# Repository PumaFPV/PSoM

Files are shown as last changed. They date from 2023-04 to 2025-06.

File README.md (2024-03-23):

# PSoM
PSoM, either Pico System On Module, or Puma System On Module for those who prefer.

The goal is to have an easy to integrate MCU + BMS for any kind of projects.
Without attaching points, the SoM is 20mm*20mm. 

## PSoM_ESP32S2_00
Hardware is done and working!

## PSoM_RP2040_00
Schematic is work in progress

##PSoM_ESP32_PICOD4_00
Schematic os work on progress

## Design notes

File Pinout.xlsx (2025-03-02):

 | Gnd |  | Power | Debug | Flash | USB | I2C | SPI | UART | ADC | DAC | IO
Pins | Alternate 1 | Alternate 2 | ESP32S2 | nRF52840 |  | Pins | Alternate 1 | Alternate 2 | ESP32S2 | nRF52840
1 | Gnd |  |  |  |  | 2 | Gnd
3 | Battery temp |  |  |  |  | 4 | Vbat
5 | SPI1_MOSI |  | IO2 | P0.06 |  | 6
7 | SPI1_MISO |  | IO3 | P0.07 |  | 8
9 | SPI1_CLK |  | IO4 | P0.08 |  | 10 | Vbus
11 | SPI1_CS0 |  | IO5 | P1.08 |  | 12
13 | SDA1 |  | IO6 | P0.00 |  | 14 | Vsys
15 | SCL1 |  | IO7 | P0.01 |  | 16
17 | INT | ADC1 | IO8 | P0.30 |  | 18 | 3V3
19 | UART1 | ADC2 | IO9 | P0.04 |  | 20
21 | UART1 | ADC3 | IO10 | P0.05 |  | 22 | Gnd
23 | GPI |  | IO11 | P1.10 |  | 24
25 | GPI |  | IO12 | P0.29 |  | 26 | BOOT0 |  | IO0
27 | GPI |  | IO13 | P0.31 |  | 28 | EN |  | EN
29 | GPI |  | IO14 | P1.13 |  | 30 | GPIO |  | IO33 | P0.26
31 | GPI |  | IO15 | P1.04 |  | 32 | GPIO |  | IO34 | P0.27
33 |  |  | IO16 | P1.15 |  | 34 | SPI2_MOSI | UART TX | IO35 | P0.14
35 | DAC1 |  | IO17 | P0.12 |  | 36 | SPI2_MISO | UART RX | IO36 | P0.15
37 | DAC2 |  | IO18 | P0.11 |  | 38 | SPI2_CLK |  | IO37 | P0.16
39 | GPIO |  | IO21 | P1.09 |  | 40 | SPI2_CS0 |  | IO38 | P0.17
41 | Gnd |  |  |  |  | 42 | SDA2 |  | IO41 | P0.24
43 | SPI_CS1 |  | SPI_CS1 | P0.20 |  | 44 | SCL2 |  | IO39 | P0.25
45 | VDD_SPI |  | VDD_SPI |  |  | 46 | INT |  | IO40 | P1.01
47 | SPI_HD |  | SPI_HD | P0.21 |  | 48 | RX0 | SWDCLK | RX0 | SDWCLK
49 | SPI_WP |  | SPI_WP | P0.23 |  | 50 | TX0 | SWDIO | TX0 | SDWDIO
51 | SPI_CS0 |  | SPI_CS0 | P0.18 |  | 52 | GPIO |  | IO42 | P1.02
53 | SPI_CLK |  | SPI_CLK | P0.19 |  | 54 | Gnd
55 | SPI_Q |  | SPI_Q | P0.22 |  | 56 | D+
57 | SPI_D |  | SPI_D | P1.00 |  | 58 | D-
59 | Gnd |  |  |  |  | 60 | Gnd

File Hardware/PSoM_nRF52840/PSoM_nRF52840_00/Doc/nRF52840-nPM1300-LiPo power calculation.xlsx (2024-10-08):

Config |  |  |  | nPM DCDC reg |  | nRF DCDC reg0 (high voltage mode) |  |  | nRF DCDC reg1 (normal voltage mode)
BMS |  | VBAT |  | VOUT |  | VIN | VOUT |  | VIN | VOUT
nPM1300 |  | 4.20 |  | 3.30 |  |  |  |  |  | 1.30
 |  | 3.80 |  | 3.30 |  |  |  |  |  | 1.30
 |  | 3.70 |  | 3.30 |  |  |  |  |  | 1.30
 |  | 3.50 |  | 3.30 |  |  |  |  |  | 1.30
 |  | 4.20 |  | 2.20 |  |  |  |  |  | 1.30
 |  | 3.80 |  | 2.20 |  |  |  |  |  | 1.30
 |  | 3.70 |  | 2.20 |  |  |  |  |  | 1.30
 |  | 3.50 |  | 2.20 |  |  |  |  |  | 1.30
 |  | 4.20 |  | 1.80 |  |  |  |  |  | 1.30
 |  | 3.80 |  | 1.80 |  |  |  |  |  | 1.30
 |  | 3.70 |  | 1.80 |  |  |  |  |  | 1.30
 |  | 3.50 |  | 1.80 |  |  |  |  |  | 1.30
 |  |  |  |  |  |  |  |  |  | 1.30
 |  |  |  |  |  |  |  |  |  | 1.30
 |  |  |  |  |  |  |  |  |  | 1.30
 |  |  |  |  |  |  |  |  |  | 1.30
BQ25101 |  | 4.20 |  |  |  |  |  |  |  | 1.30
 |  | 3.80 |  |  |  |  |  |  |  | 1.30
 |  | 3.70 |  |  |  |  |  |  |  | 1.30
 |  | 3.50 |  |  |  |  |  |  |  | 1.30
 | vbat | > | npm buck1 | > | nrf vdd | > | reg1 | >1v3
 |  |  | npm buck2 | > | 3v3
 | vbat | > | bq | > | nrf vddH | > | reg0 | > | 3v3
 |  |  |  |  |  |  |  | > | reg1 | > | 1v3

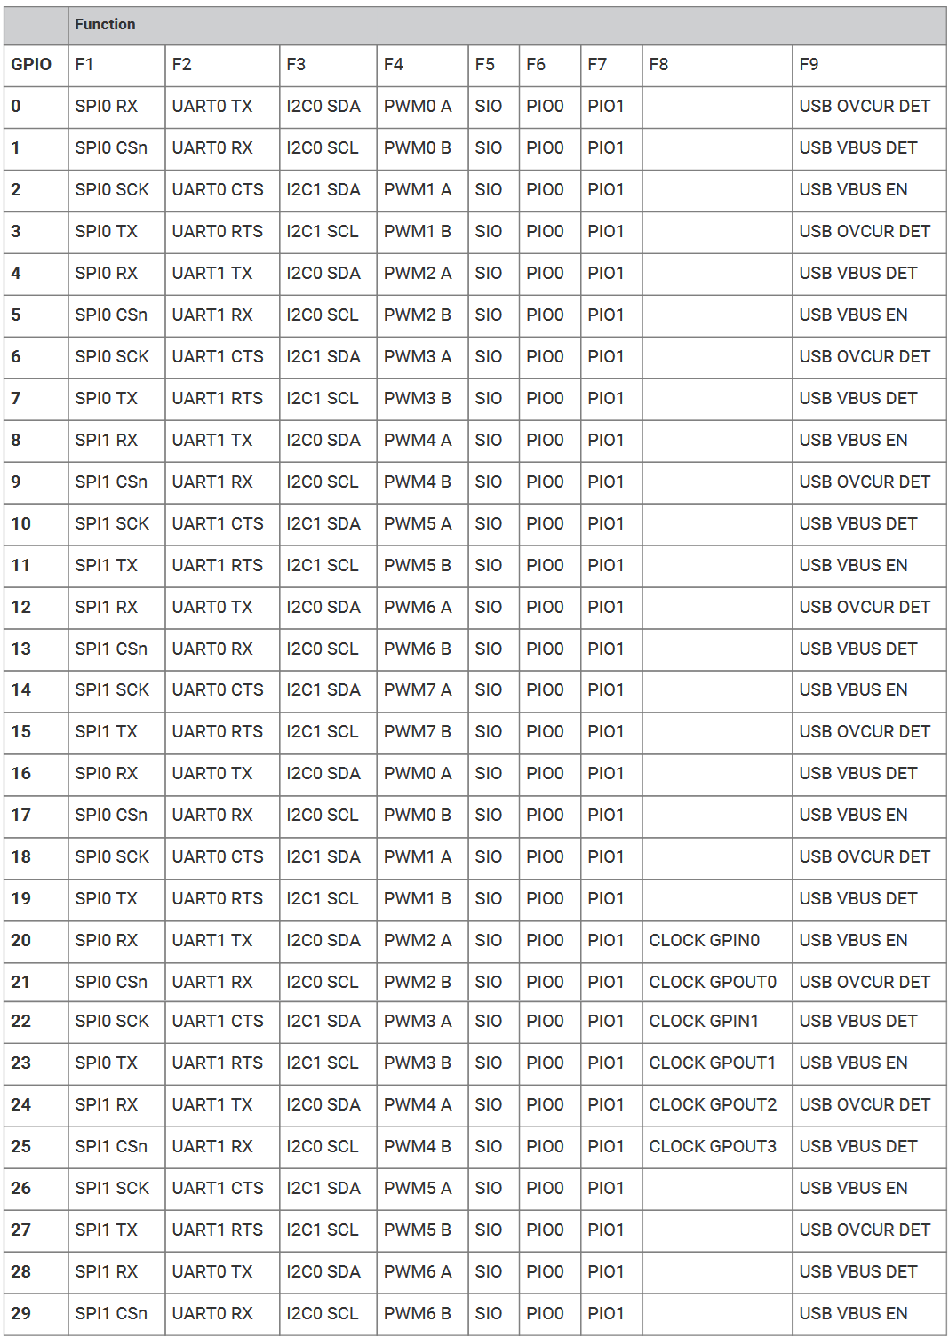
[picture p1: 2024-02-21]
Hardware/PSoM_RP2040/PSoM_RP2040_00/Doc/pinout.png

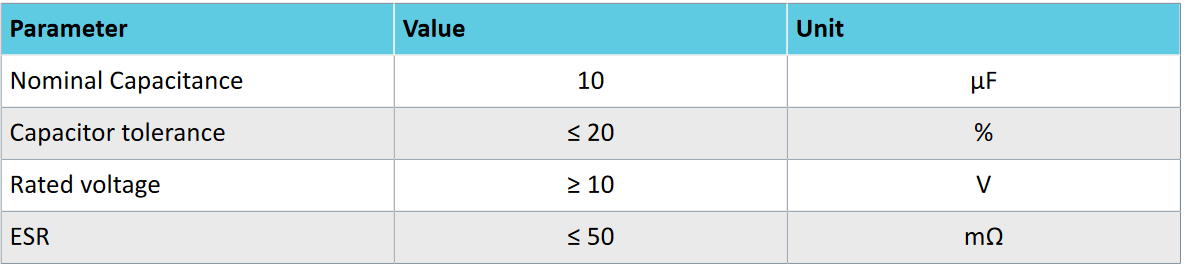
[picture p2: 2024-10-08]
Hardware/PSoM_nRF52840/PSoM_nRF52840_00/Doc/nPM1300 capacitor selection.png

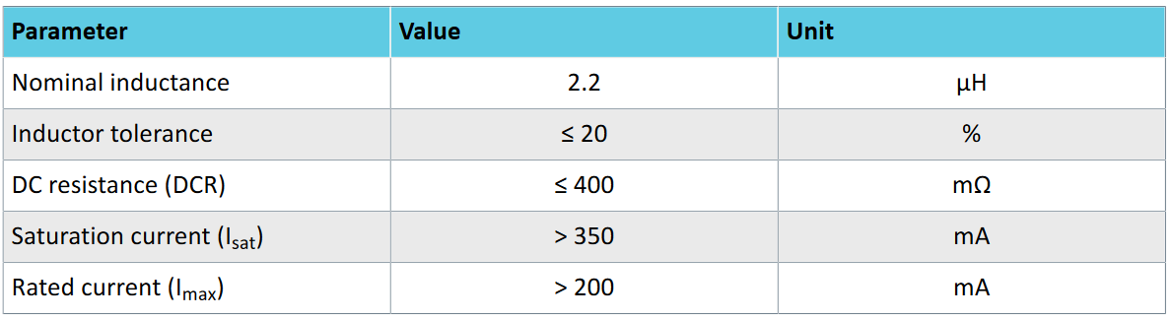
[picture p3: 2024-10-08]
Hardware/PSoM_nRF52840/PSoM_nRF52840_00/Doc/nPM1300 inductor selection.png

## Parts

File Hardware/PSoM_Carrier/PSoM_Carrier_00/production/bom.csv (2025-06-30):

Designator | Footprint | Quantity | Value | LCSC Part #
CS1-P43 | TestPoint_Pad_1.0x1.0mm | 1 | TestPoint
J1 | USB4510031A | 1 | USB4510-03-1-A
J10, J17 | PinHeader_1x06_P2.54mm_Vertical | 2 | Conn_01x06
J11, J18, J20, J21, J7, J9 | PinHeader_1x04_P2.54mm_Vertical | 6 | Conn_01x04
J12, J15, J19 | PinHeader_1x03_P2.54mm_Vertical | 3 | Conn_01x03
J13, J16, J2, J3, J4, J5 | PinHeader_1x02_P2.54mm_Vertical | 6 | Conn_01x02
J14, J8 | PinHeader_1x12_P2.54mm_Vertical | 2 | Conn_01x12
J22 | PinHeader_1x05_P2.54mm_Vertical | 1 | Conn_01x05
J23 | PSoM_ESP32S2_00 | 1 | PSoM_ESP32S2_Carrier_Board
J6 | 532610371 | 1 | 53261-0371
R1, R2 | 0402 | 2 | 5k1
S1, S2 | SKRPABE010 | 2 | SKRPABE010
SW1 | 450405020524 | 1 | 450405020524
U1 | SON127P600X500X80-9N-D | 1 | W25Q128JVPIQ_TR

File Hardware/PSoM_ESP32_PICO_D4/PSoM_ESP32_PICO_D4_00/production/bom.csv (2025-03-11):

Designator | Footprint | Quantity | Value | LCSC Part #
ANT401 | ANTC3216X140N | 1 | 2450AT18A100E
C101, C402, C405 | 0201 | 3 | 100n
C201, C203 | 0603 | 2 | 4u7
C202 | 0603 | 1 | 1u
C301, C302 | 0603 | 2 | 2u2
C401 | 0603 | 1 | 10u
C403, C404 | 0201 | 2 | C
D201, D202, D401 | 0402 | 3 | LED
J101 | DF40C-60DP-0.4V(51) | 1 | DF40C-60DP-0.4V(51)
L401 | 0201 | 1 | L
R1, R2 | 0402 | 2 | R
R103 | 0201 | 1 | 220k
R104 | 0201 | 1 | 470k
R201 | 0402 | 1 | 0
R202 | 0402 | 1 | 36k5
R203 | 0402 | 1 | 590
R204 | 0402 | 1 | 1k1
R205, R206 | 0402 | 2 | 1k5
R207 | 0402 | 1 | 100k
R301 | 0201 | 1 | 0k
R401 | 0402 | 1 | 2k
R402 | 0201 | 1 | 10k
R408, R409 | 0201 | 2 | nu
SW401, SW402 | B3U-1000P | 2 | SW_Push
U201 | QFN50P300X300X100-17N-D | 1 | BQ24075RGTR
U301 | SON40P120X120X60-7N-D | 1 | MIC5528-3.3YMT-T5
U401 | ESP32-PICO-D4_1 | 1 | ESP32-PICO-D4

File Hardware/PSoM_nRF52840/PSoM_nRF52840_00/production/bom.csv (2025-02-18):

Designator | Footprint | Quantity | Value | LCSC Part #
C201, C205, C414, C415 | 0402 | 4 | 1u
C202, C203, C204, L402 | 0603 | 4 | 10u
C206, L201, L202 | 0603 | 3 | 2u2
C207, C208 | 0402 | 2 | 10u
C401, C402 | 0201 | 2 | 12p
C403 | 0201 | 1 | 0p8
C404 | 0201 | 1 | 0p5
C405, C407, C408, C412, C461 | 0201 | 5 | 100n
C406, C420, C421 | 0603 | 3 | 4u7
C409 | 0201 | 1 | 820p
C410, C413 | 0402 | 2 | nc
C411 | 0201 | 1 | 100p
C416 | 0402 | 1 | 47n
D201, D202, D203 | 0402 | 3 | LED
J1 | usb-c-pcb | 1 | Bare PCB USB C
J101 | DF40C-60DP-0.4V(51) | 1 | DF40C-60DP-0.4V(51)
J2 | u.fl | 1 | U.FL-R-SMT-1_40_
J401, J402 | SolderWirePad_1x01_SMD_1x2mm | 2 | Conn_01x01_Pin
L401 | 0201 | 1 | 4n7
L403 | 0402 | 1 | 15n
R203 | 0201 | 1 | 47k
R204 | 0201 | 1 | 470k
R205, R461 | 0201 | 2 | 10k
SW461 | B3U-1000P | 1 | SW_Push
U201 | NPM1300-QEAA-R | 1 | NPM1300-QEAA-R
U401 | Nordic_AQFN-73-1EP_7x7mm_P0.5mm | 1 | nRF52840-QIAA-aQFN73
Y401 | 830108161301_1.6x1.2mm | 1 | 830108161301

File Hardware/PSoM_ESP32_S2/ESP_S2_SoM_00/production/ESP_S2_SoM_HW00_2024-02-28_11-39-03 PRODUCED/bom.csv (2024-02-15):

Designator | Footprint | Quantity | Value | LCSC Part #
ANT401 | ANTC3216X140N | 1 | 2450AT18A100E
C101, C403, C404, C405, C408, C411, C412, C414, C415, C416 | 0201 | 10 | 100n
C201, C203 | 0603 | 2 | 4u7
C202 | 0603 | 1 | 1u
C301, C302 | 0603 | 2 | 2u2
C401, C402 | 0201 | 2 | 15p
C406, C407 | 0201 | 2 | C
C409 | 0603 | 1 | 10u
C410, C413 | 0402 | 2 | 1u
D201, D202, D401 | 0402 | 3 | LED
J101 | DF40C-60DP-0.4V(51) | 1 | DF40C-60DP-0.4V(51)
J102 | usb-c-pcb | 1 | Bare PCB USB C
L401 | 0201 | 1 | L
R1, R2 | 0402 | 2 | R
R101, R102 | 0201 | 2 | 5.1k
R103 | 0201 | 1 | 220k
R104 | 0201 | 1 | 470k
R201 | 0402 | 1 | 0
R202 | 0402 | 1 | 36k5
R203 | 0402 | 1 | 590
R204 | 0402 | 1 | 1k1
R205, R206 | 0402 | 2 | 1k5
R207 | 0402 | 1 | 100k
R301 | 0201 | 1 | 0k
R401 | 0201 | 1 | 0
R402 | 0402 | 1 | 2k
R403, R404 | 0201 | 2 | 10k
R405, R406, R407, R408 | 0201 | 4 | nu
SW401, SW402 | B3U-1000P | 2 | SW_Push
U201 | QFN50P300X300X100-17N-D | 1 | BQ24075RGTR
U301 | SON40P120X120X60-7N-D | 1 | MIC5528-3.3YMT-T5
U401 | QFN40P700X700X90-57N-D | 1 | ESP32-S2FH4
Y601 | Crystal_SMD_2016-4Pin_2.0x1.6mm | 1 | Crystal_GND24_Small

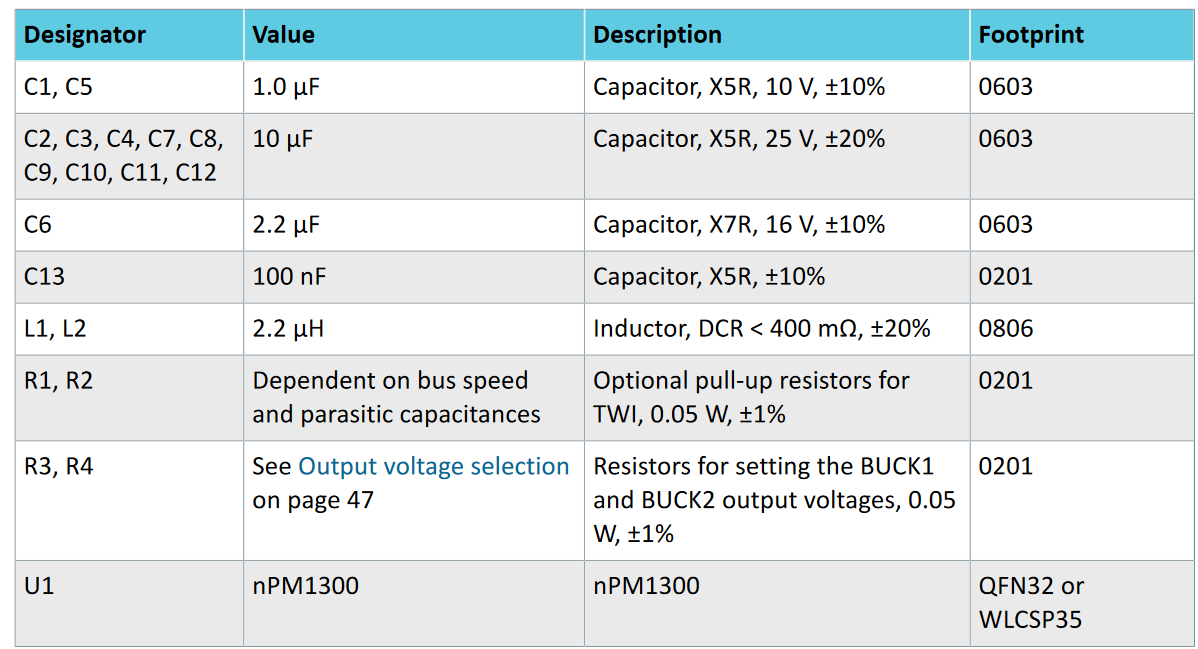
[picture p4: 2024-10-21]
Hardware/PSoM_nRF52840/PSoM_nRF52840_00/Doc/nPM1300 component selection.png

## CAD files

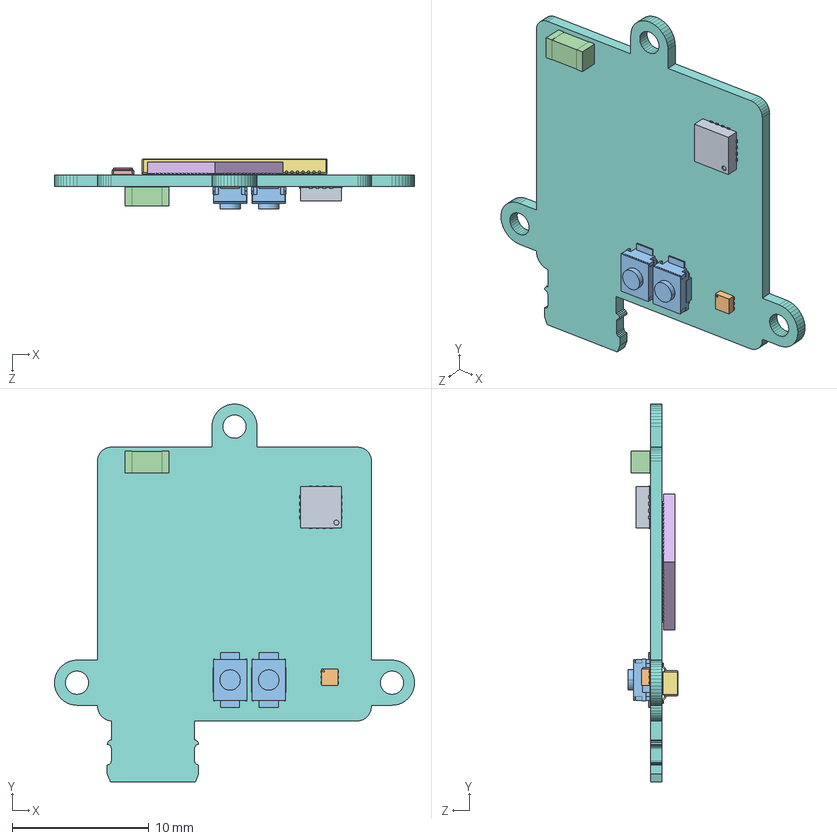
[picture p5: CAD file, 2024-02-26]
Hardware/PSoM_ESP32_PICO_D4/PSoM_ESP32_PICO_D4_00/Mecha/PSoM_ESP32S2_00.SLDASM
26.3 x 27.6 x 3.65 mm
COMPOUND.step
COMPOUND-0.step
SOLID.step x 2
COMPOUND-1.step
COMPOUND-2.step
COMPOUND-3.step
SOLID-4.step
PCB.step

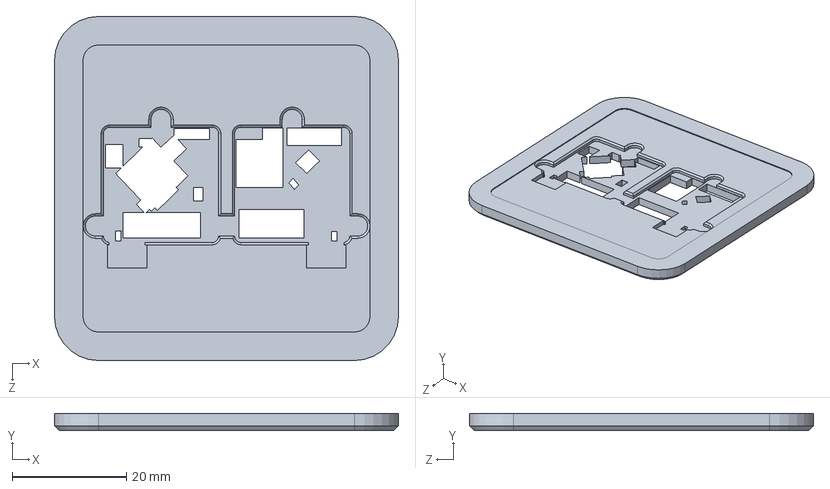
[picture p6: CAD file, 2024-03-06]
Hardware/PSoM_ESP32_S2/ESP_S2_SoM_00/production/stencil holder.SLDPRT
60.3 x 3.00 x 60.3 mm

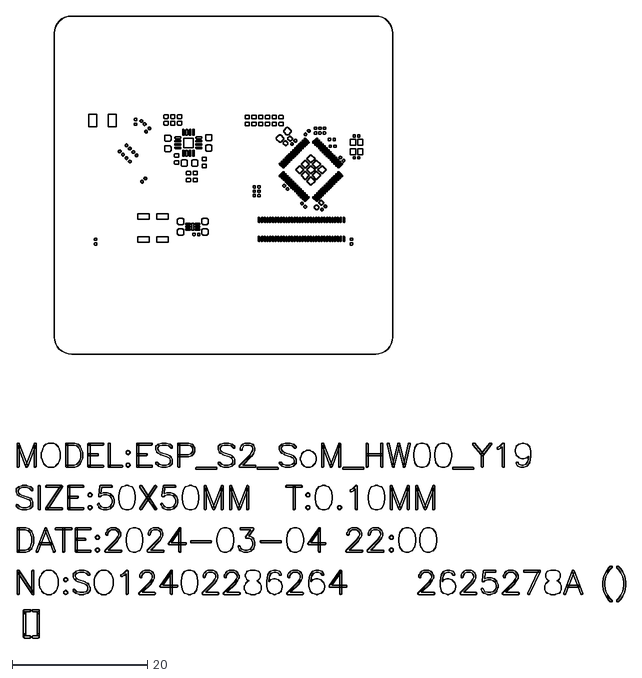
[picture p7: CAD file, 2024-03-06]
Hardware/PSoM_ESP32_S2/ESP_S2_SoM_00/production/SO12402286264/so12402286264A.DXF
90.2 x 91.9

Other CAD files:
Hardware/PSoM_ESP32_PICO_D4/PSoM_ESP32_PICO_D4_00/Mecha/PSoM_ESP32S2_00.DXF
Hardware/PSoM_ESP32_PICO_D4/PSoM_ESP32_PICO_D4_00/Mecha/PSoM_ESP32S2_00.SLDDRW
Hardware/PSoM_ESP32_S2/ESP_S2_SoM_00/production/stencil holder.STL

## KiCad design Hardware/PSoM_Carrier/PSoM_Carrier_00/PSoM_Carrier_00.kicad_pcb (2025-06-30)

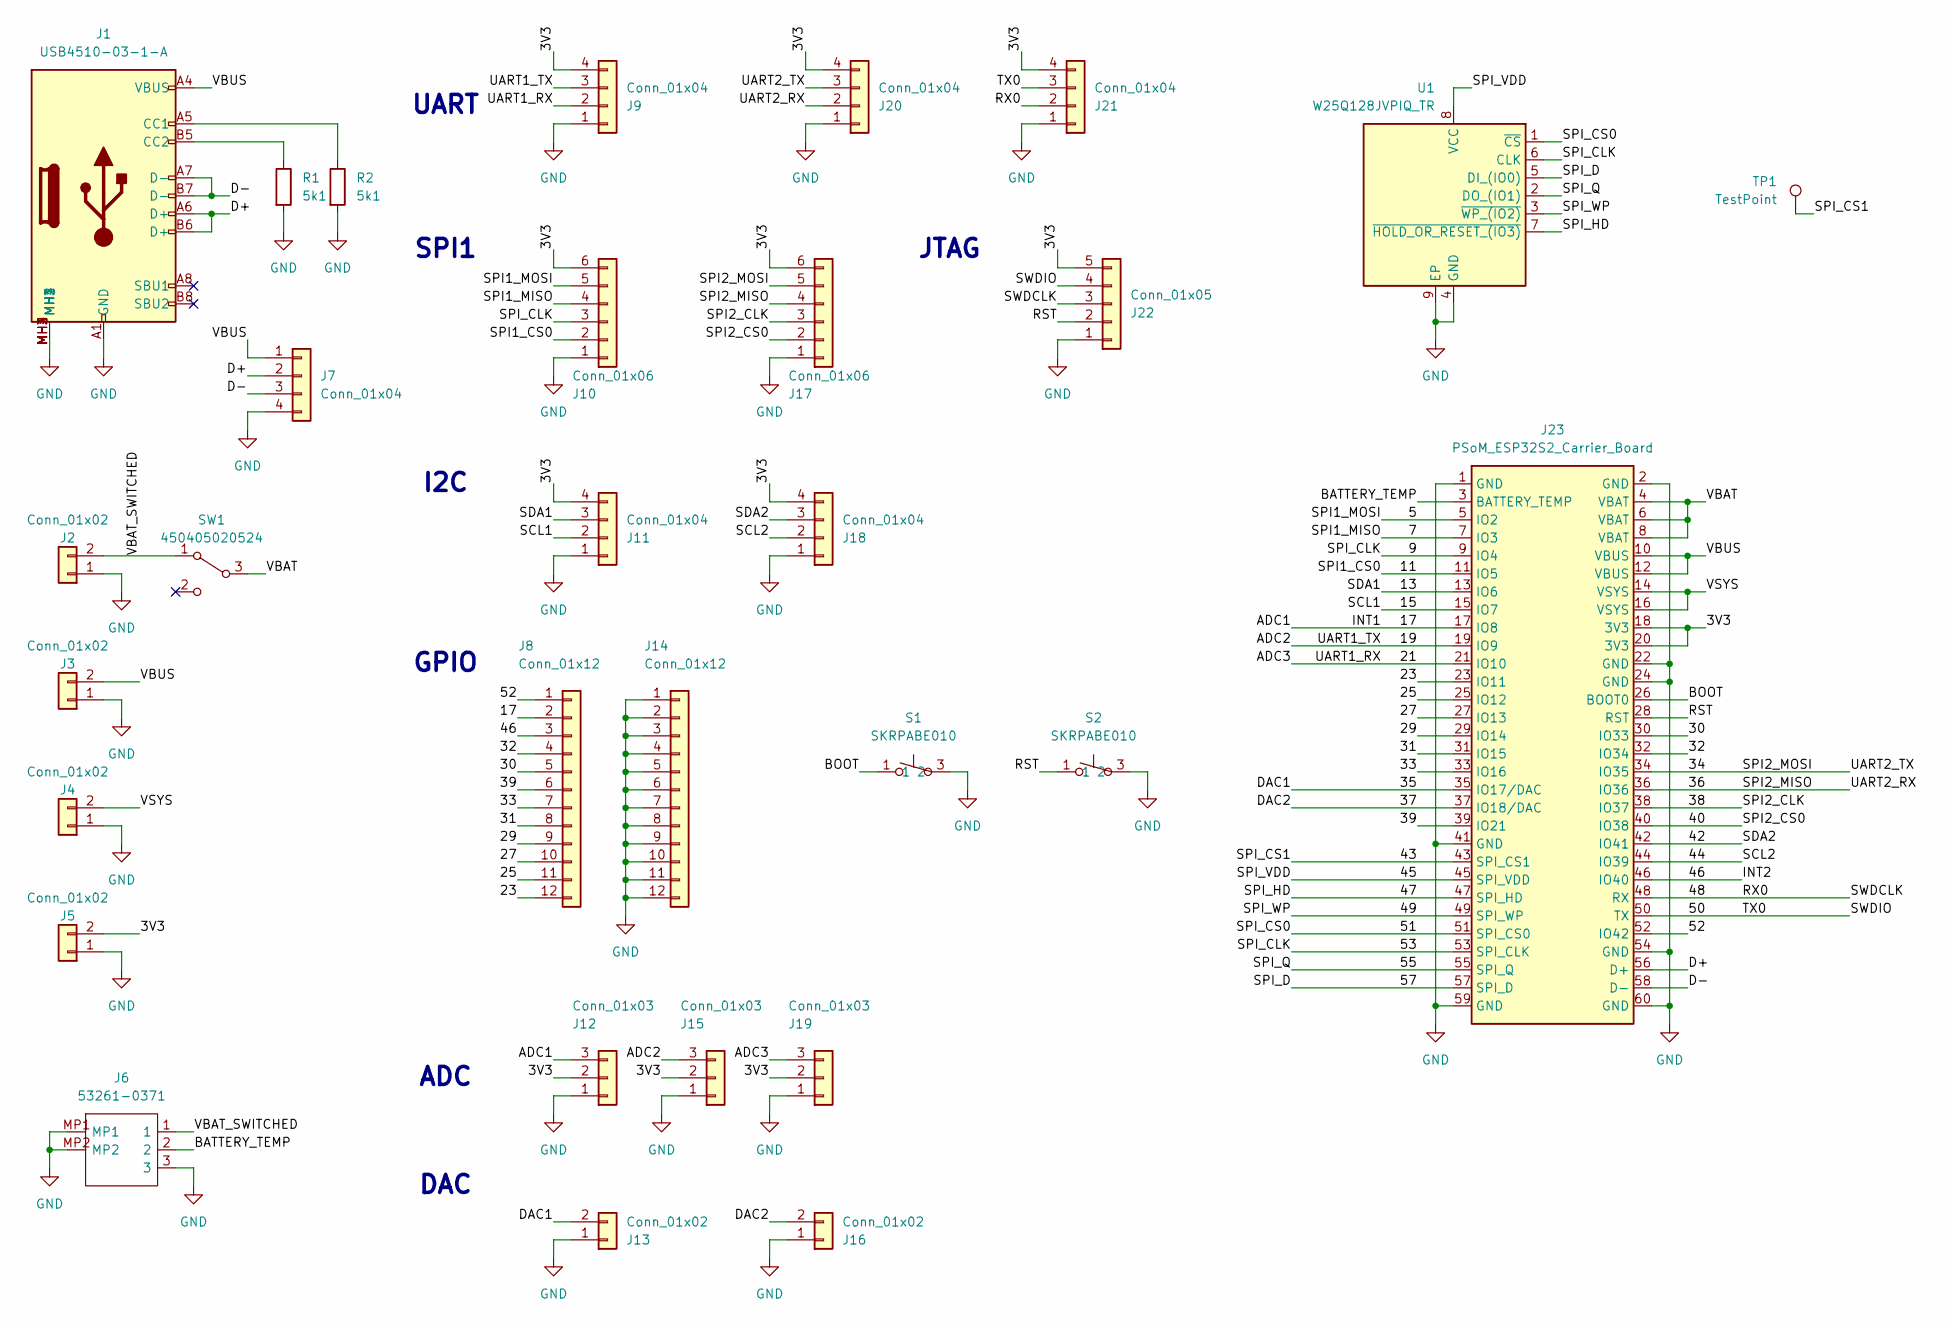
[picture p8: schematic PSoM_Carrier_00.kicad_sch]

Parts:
J1: USB4510-03-1-A; USB4510031A; Mouser Part Number 640-USB4510031A
J2, J3, J4, J5, J13, J16: Conn_01x02; PinHeader_1x02_P2.54mm_Vertical
J6: 53261-0371; 532610371; Mouser Part Number 538-53261-0371
J7, J9, J11, J18, J20, J21: Conn_01x04; PinHeader_1x04_P2.54mm_Vertical
J8, J14: Conn_01x12; PinHeader_1x12_P2.54mm_Vertical
J10, J17: Conn_01x06; PinHeader_1x06_P2.54mm_Vertical
J12, J15, J19: Conn_01x03; PinHeader_1x03_P2.54mm_Vertical
J22: Conn_01x05; PinHeader_1x05_P2.54mm_Vertical
J23: PSoM_ESP32S2_Carrier_Board; PSoM_ESP32S2_00
R1, R2: 5k1; R_0402_1005Metric
S1, S2: SKRPABE010; Mouser Part Number 688-SKRPAB
SW1: 450405020524
TP1: TestPoint; TestPoint_Pad_1.0x1.0mm
U1: W25Q128JVPIQ_TR; SON127P600X500X80-9N-D; Mouser Part Number 454-W25Q128JVPIQTR

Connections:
/3V3: J5.2, J9.4, J10.6, J11.4, J12.2, J15.2, J17.6, J18.4, J19.2, J20.4, J21.4, J22.5, J23.18 (3V3), J23.20 (3V3)
/5: J10.5, J23.5 (IO2)
/7: J10.4, J23.7 (IO3)
/11: J10.2, J23.11 (IO5)
/13: J11.3, J23.13 (IO6)
/15: J11.2, J23.15 (IO7)
/17: J8.2, J12.3, J23.17 (IO8)
/19: J9.3, J15.3, J23.19 (IO9)
/21: J9.2, J19.3, J23.21 (IO10)
/23: J8.12, J23.23 (IO11)
/25: J8.11, J23.25 (IO12)
/27: J8.10, J23.27 (IO13)
/29: J8.9, J23.29 (IO14)
/30: J8.5, J23.30 (IO33)
/31: J8.8, J23.31 (IO15)
/32: J8.4, J23.32 (IO34)
/33: J8.7, J23.33 (IO16)
/34: J17.5, J20.3, J23.34 (IO35)
/35: J13.2, J23.35 (IO17/DAC)
/36: J17.4, J20.2, J23.36 (IO36)
/37: J16.2, J23.37 (IO18/DAC)
/38: J17.3, J23.38 (IO37)
/39: J8.6, J23.39 (IO21)
/40: J17.2, J23.40 (IO38)
/42: J18.3, J23.42 (IO41)
/43: J23.43 (SPI_CS1), TP1.1; also elsewhere on the board
/44: J18.2, J23.44 (IO39)
/45: J23.45 (SPI_VDD), U1.8 (VCC)
/46: J8.3, J23.46 (IO40)
/47: J23.47 (SPI_HD), U1.7 (~HOLD_OR_RESET_(IO3))
/48: J21.2, J22.3, J23.48 (RX)
/49: J23.49 (SPI_WP), U1.3 (~WP_(IO2))
/50: J21.3, J22.4, J23.50 (TX)
/51: J23.51 (SPI_CS0), U1.1 (~CS)
/52: J8.1, J23.52 (IO42)
/53: J10.3, J23.9 (IO4), J23.53 (SPI_CLK), U1.6 (CLK)
/55: J23.55 (SPI_Q), U1.2 (DO_(IO1))
/57: J23.57 (SPI_D), U1.5 (DI_(IO0))
/BATTERY_TEMP: J6.2, J23.3 (BATTERY_TEMP)
/BOOT: J23.26 (BOOT0), S1.1, S1.2 (1)
/D+: J1.A6 (D+), J1.B6 (D+), J7.2, J23.56 (D+)
/D-: J1.A7 (D-), J1.B7 (D-), J7.3, J23.58 (D-)
/RST: J22.2, J23.28 (RST), S2.1, S2.2 (1)
/VBAT: J23.4 (VBAT), J23.6 (VBAT), J23.8 (VBAT), SW1.3 (B)
/VBAT_SWITCHED: J2.2, J6.1, SW1.1 (A)
/VBUS: J1.A4 (VBUS), J1.A9 (VBUS), J1.B4 (VBUS), J1.B9 (VBUS), J3.2, J7.1, J23.10 (VBUS), J23.12 (VBUS)
/VSYS: J4.2, J23.14 (VSYS), J23.16 (VSYS)
GND: J1.A1 (GND), J1.A12 (GND), J1.B1 (GND), J1.B12 (GND), J1.MH1, J1.MH2, J1.MH3, J1.MH4, J2.1, J3.1, J4.1, J5.1, J6.3, J6.MP1, J6.MP2, J7.4, J9.1, J10.1, J11.1, J12.1, J13.1, J14.1, J14.2, J14.3, J14.4, J14.5, J14.6, J14.7, J14.8, J14.9, J14.10, J14.11, J14.12, J15.1, J16.1, J17.1, J18.1, J19.1, J20.1, J21.1, J22.1, J23.1 (GND), J23.2 (GND), J23.22 (GND), J23.24 (GND), J23.41 (GND), J23.54 (GND), J23.59 (GND), J23.60 (GND), R1.2, R2.2, S1.3 (2), S1.4 (2), S2.3 (2), S2.4 (2), U1.4 (GND), U1.9 (EP)
unnamed: J1.A5 (CC1), R2.1
unnamed: J1.B5 (CC2), R1.1

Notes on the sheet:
ADC
DAC
I2C
JTAG
SPI1
GPIO
UART

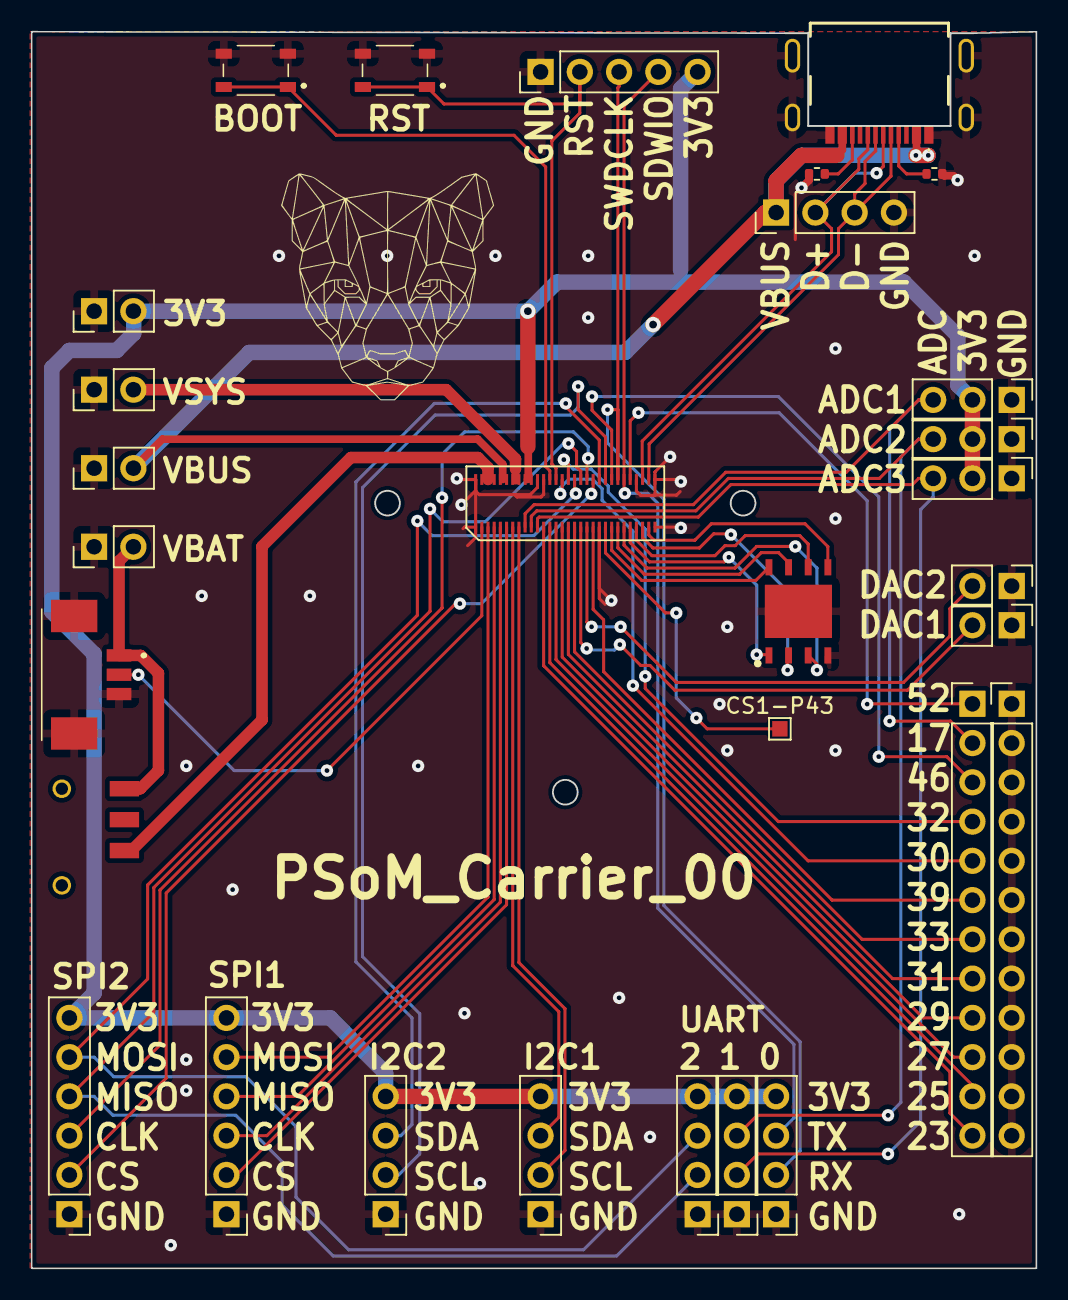
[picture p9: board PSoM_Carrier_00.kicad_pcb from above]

Board: 2 copper layers, 65.0 x 80.0 mm, 30 parts (0 on the bottom side), 50 nets.

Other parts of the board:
CS1-P43: TestPoint; TestPoint_Pad_1.0x1.0mm

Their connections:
/43: CS1-P43.1; also elsewhere on the board

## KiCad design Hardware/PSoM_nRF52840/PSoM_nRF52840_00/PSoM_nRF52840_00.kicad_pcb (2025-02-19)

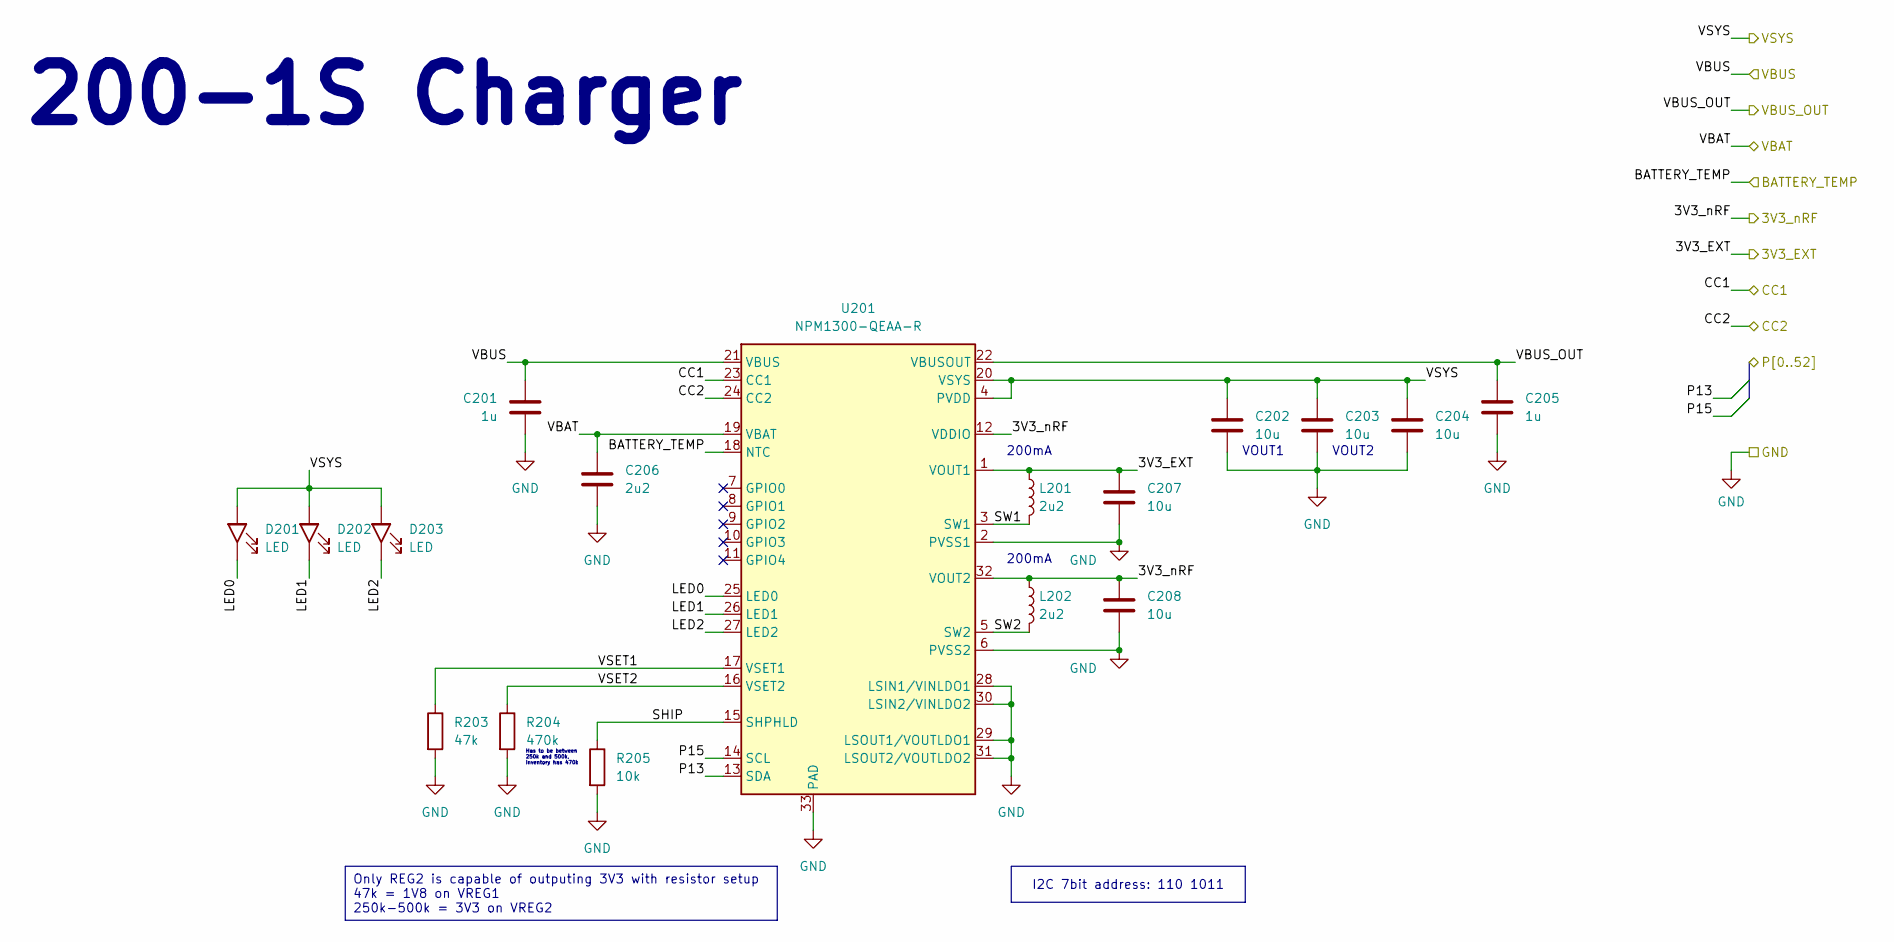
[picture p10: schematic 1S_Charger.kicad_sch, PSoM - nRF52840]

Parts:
C201, C205: 1u; C_0402_1005Metric
C202, C203, C204: 10u; C_0603_1608Metric
C206: 2u2; C_0603_1608Metric
C207: 10u; C_0402_1005Metric
C208: 10u; C_0402_1005Metric_Pad0.74x0.62mm_HandSolder
D201, D202, D203: LED; LED_0402_1005Metric
L201, L202: 2u2; L_0603_1608Metric
R203: 47k; R_0201_0603Metric
R204: 470k; R_0201_0603Metric
R205: 10k; R_0201_0603Metric
U201: NPM1300-QEAA-R; Mouser Part Number 949-NPM1300-QEAA-R

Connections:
+3V3: C207.1, L201.1, U201.1 (VOUT1); also elsewhere on the board
/100_Connectors/BATTERY_TEMP: U201.18 (NTC); also elsewhere on the board
/100_Connectors/CC1: U201.23 (CC1); also elsewhere on the board
/100_Connectors/CC2: U201.24 (CC2); also elsewhere on the board
/100_Connectors/VBAT: C206.1, U201.19 (VBAT); also elsewhere on the board
/100_Connectors/VSYS: C202.1, C203.1, C204.1, D201.1 (A), D202.1 (A), D203.1 (A), U201.4 (PVDD), U201.20 (VSYS); also elsewhere on the board
/200_1S_Charger/3V3_nRF: C208.1, L202.1, U201.12 (VDDIO), U201.32 (VOUT2); also elsewhere on the board
/200_1S_Charger/LED0: D201.2 (K), U201.25 (LED0)
/200_1S_Charger/LED1: D202.2 (K), U201.26 (LED1)
/200_1S_Charger/LED2: D203.2 (K), U201.27 (LED2)
/200_1S_Charger/SHIP: R205.1, U201.15 (SHPHLD)
/200_1S_Charger/SW1: L201.2, U201.3 (SW1)
/200_1S_Charger/SW2: L202.2, U201.5 (SW2)
/200_1S_Charger/VBUS_OUT: C205.1, U201.22 (VBUSOUT); also elsewhere on the board
/200_1S_Charger/VSET1: R203.1, U201.17 (VSET1)
/200_1S_Charger/VSET2: R204.1, U201.16 (VSET2)
GND: C201.1, C202.2, C203.2, C204.2, C205.2, C206.2, C207.2, C208.2, R203.2, R204.2, R205.2, U201.2 (PVSS1), U201.6 (PVSS2), U201.28 (LSIN1/VINLDO1), U201.29 (LSOUT1/VOUTLDO1), U201.30 (LSIN2/VINLDO2), U201.31 (LSOUT2/VOUTLDO2), U201.33 (PAD); also elsewhere on the board
P13: U201.13 (SDA); also elsewhere on the board
P15: U201.14 (SCL); also elsewhere on the board
VBUS: C201.2, U201.21 (VBUS); also elsewhere on the board

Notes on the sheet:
Only REG2 is capable of outputing 3V3 with resistor setup 47k = 1V8 on VREG1 250k-500k = 3V3 on VREG2
I2C 7bit address: 110 1011
200-1S Charger
200mA
Has to be between 250k and 500k, Inventory has 470k
VOUT1
VOUT2

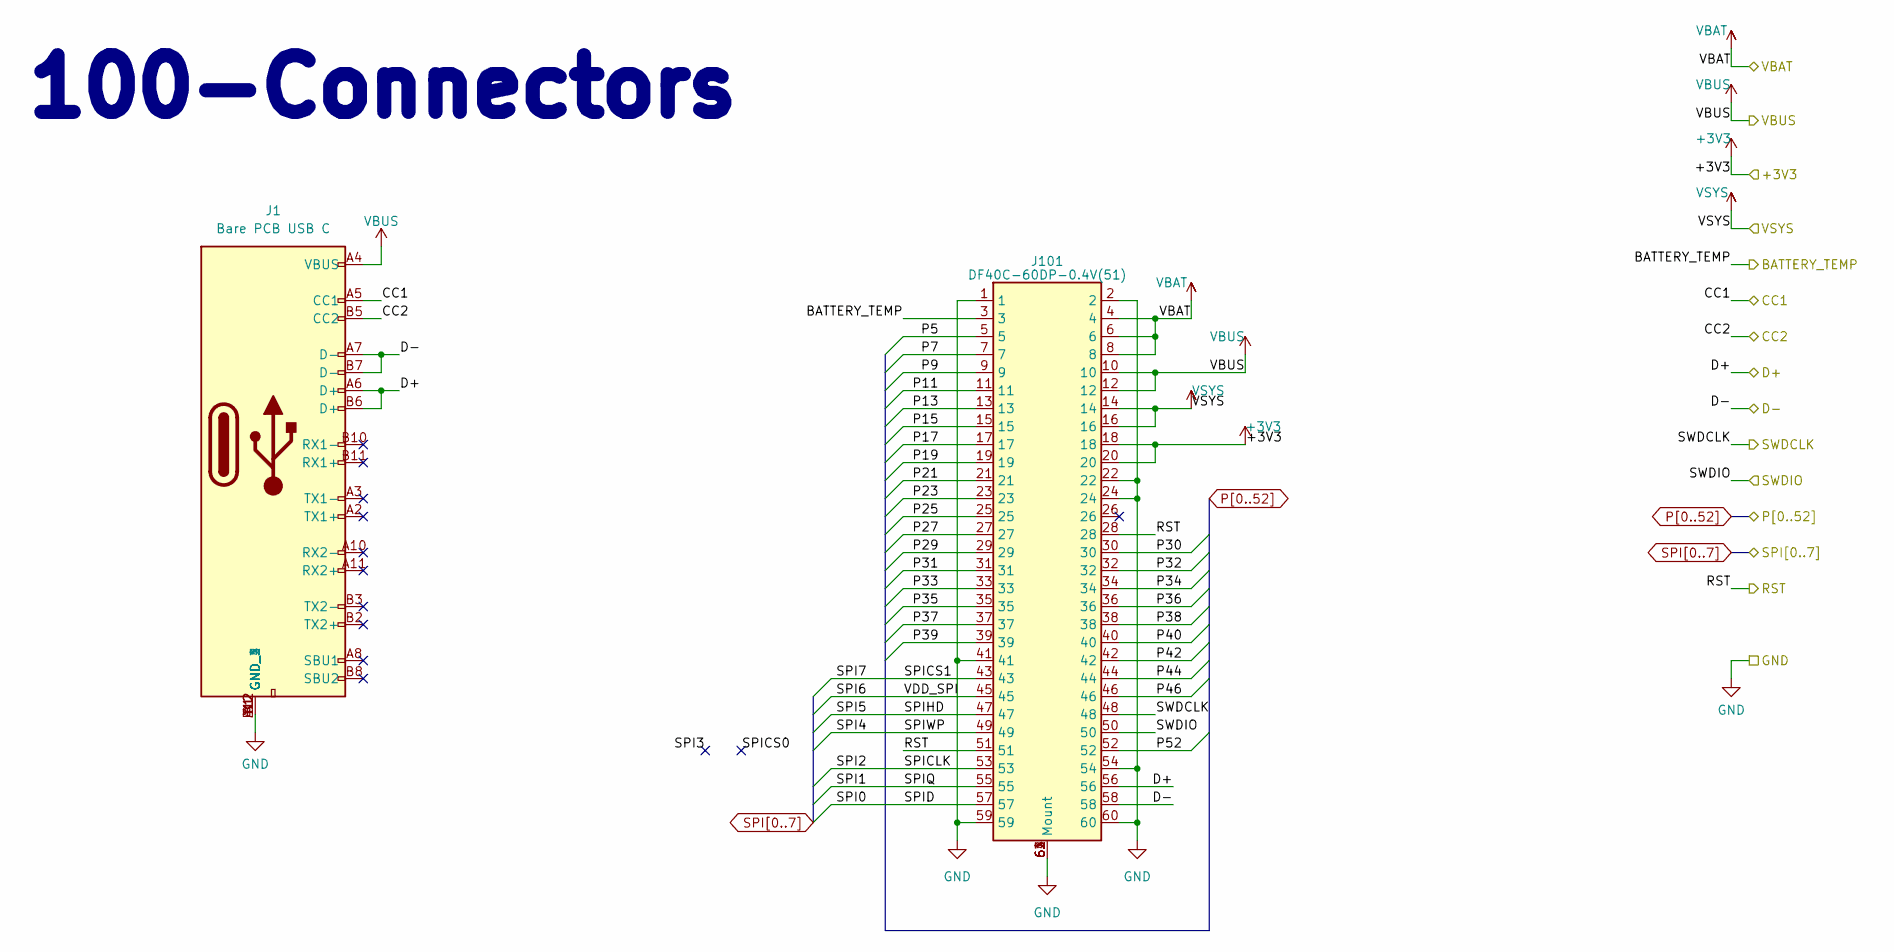
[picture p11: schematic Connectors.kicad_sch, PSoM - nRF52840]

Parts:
J1: Bare PCB USB C; usb-c-pcb; Mouser Part Number 640-USB4510031A
J101: DF40C-60DP-0.4V(51)

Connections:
+3V3: J101.18, J101.20; also elsewhere on the board
/100_Connectors/BATTERY_TEMP: J101.3; also elsewhere on the board
/100_Connectors/CC1: J1.A5 (CC1); also elsewhere on the board
/100_Connectors/CC2: J1.B5 (CC2); also elsewhere on the board
/100_Connectors/D+: J1.A6 (D+), J1.B6 (D+), J101.56; also elsewhere on the board
/100_Connectors/D-: J1.A7 (D-), J1.B7 (D-), J101.58; also elsewhere on the board
/100_Connectors/RST: J101.28, J101.51; also elsewhere on the board
/100_Connectors/SWDCLK: J101.48; also elsewhere on the board
/100_Connectors/SWDIO: J101.50; also elsewhere on the board
/100_Connectors/VBAT: J101.4, J101.6, J101.8; also elsewhere on the board
/100_Connectors/VSYS: J101.14, J101.16; also elsewhere on the board
GND: J1.A1 (GND_1), J1.A12 (GND_2), J1.B1 (GND_3), J1.B12 (GND_4), J101.1, J101.2, J101.22, J101.24, J101.41, J101.54, J101.59, J101.60, J101.61 (Mount), J101.62, J101.63, J101.64; also elsewhere on the board
P5: J101.5; also elsewhere on the board
P7: J101.7; also elsewhere on the board
P9: J101.9; also elsewhere on the board
P11: J101.11; also elsewhere on the board
P13: J101.13; also elsewhere on the board
P15: J101.15; also elsewhere on the board
P17: J101.17; also elsewhere on the board
P19: J101.19; also elsewhere on the board
P21: J101.21; also elsewhere on the board
P23: J101.23; also elsewhere on the board
P25: J101.25; also elsewhere on the board
P27: J101.27; also elsewhere on the board
P29: J101.29; also elsewhere on the board
P30: J101.30; also elsewhere on the board
P31: J101.31; also elsewhere on the board
P32: J101.32; also elsewhere on the board
P33: J101.33; also elsewhere on the board
P34: J101.34; also elsewhere on the board
P35: J101.35; also elsewhere on the board
P36: J101.36; also elsewhere on the board
P37: J101.37; also elsewhere on the board
P38: J101.38; also elsewhere on the board
P39: J101.39; also elsewhere on the board
P40: J101.40; also elsewhere on the board
P42: J101.42; also elsewhere on the board
P44: J101.44; also elsewhere on the board
P46: J101.46; also elsewhere on the board
P52: J101.52; also elsewhere on the board
SPI0: J101.57; also elsewhere on the board
SPI1: J101.55; also elsewhere on the board
SPI2: J101.53; also elsewhere on the board
SPI4: J101.49; also elsewhere on the board
SPI5: J101.47; also elsewhere on the board
SPI6: J101.45
SPI7: J101.43; also elsewhere on the board
VBUS: J1.A4 (VBUS), J1.A9 (VBUS), J1.B4 (VBUS), J1.B9 (VBUS), J101.10, J101.12; also elsewhere on the board

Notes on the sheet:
100-Connectors

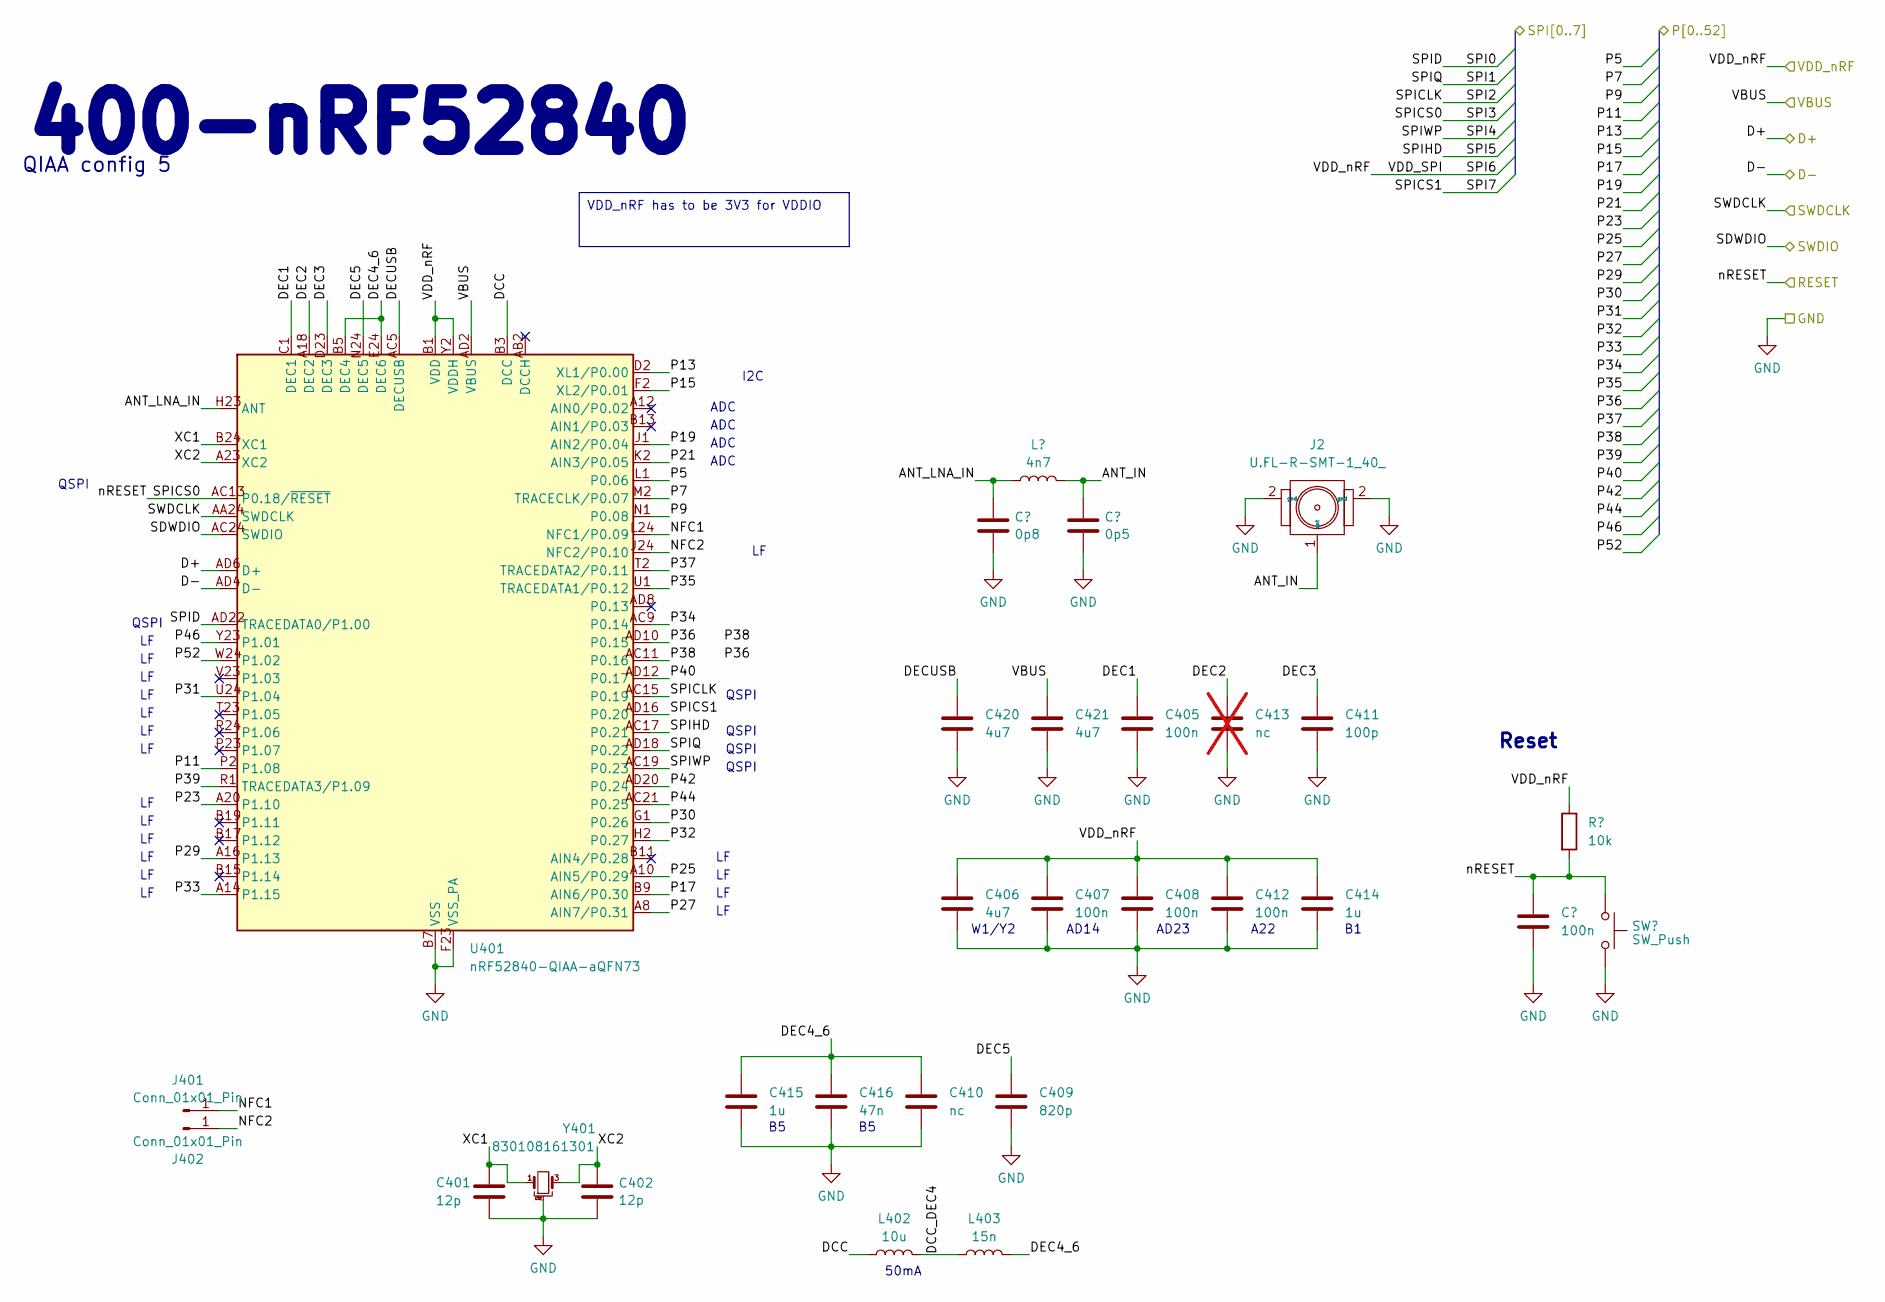
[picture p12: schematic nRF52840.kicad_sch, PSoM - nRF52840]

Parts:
C401, C402: 12p; C_0201_0603Metric
C403: 0p8; C_0201_0603Metric
C404: 0p5; C_0201_0603Metric
C405, C407, C408, C412, C461: 100n; C_0201_0603Metric
C406, C420, C421: 4u7; C_0603_1608Metric
C409: 820p; C_0201_0603Metric
C410: nc; C_0402_1005Metric
C411: 100p; C_0201_0603Metric
C413: nc; C_0402_1005Metric; not fitted
C414, C415: 1u; C_0402_1005Metric
C416: 47n; C_0402_1005Metric
J2: U.FL-R-SMT-1_40_; u.fl; Mouser Part Number 798-UFLRSMT140
J401, J402: Conn_01x01_Pin; SolderWirePad_1x01_SMD_1x2mm
L401: 4n7; L_0201_0603Metric
L402: 10u; L_0603_1608Metric
L403: 15n; L_0402_1005Metric
R461: 10k; R_0201_0603Metric
SW461: SW_Push; B3U-1000P
U401: nRF52840-QIAA-aQFN73; Nordic_AQFN-73-1EP_7x7mm_P0.5mm
Y401: 830108161301; 830108161301_1.6x1.2mm

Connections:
/100_Connectors/D+: U401.AD6 (D+); also elsewhere on the board
/100_Connectors/D-: U401.AD4 (D-); also elsewhere on the board
/100_Connectors/RST: C461.1, R461.2, SW461.1, U401.AC13 (P0.18/~RESET); also elsewhere on the board
/100_Connectors/SWDCLK: U401.AA24 (SWDCLK); also elsewhere on the board
/100_Connectors/SWDIO: U401.AC24 (SWDIO); also elsewhere on the board
/200_1S_Charger/3V3_nRF: C406.1, C407.1, C408.1, C412.1, C414.1, R461.1, U401.A22 (VDD), U401.AD14 (VDD), U401.AD23 (VDD), U401.B1 (VDD), U401.W1 (VDD), U401.Y2 (VDDH); also elsewhere on the board
/200_1S_Charger/VBUS_OUT: C421.1, U401.AD2 (VBUS); also elsewhere on the board
/400-nRF52840/ANT_IN: C404.1, J2.1 (ant), L401.1
/400-nRF52840/ANT_LNA_IN: C403.1, L401.2, U401.H23 (ANT)
/400-nRF52840/DCC: L402.1, U401.B3 (DCC)
/400-nRF52840/DCC_DEC4: L402.2, L403.1
/400-nRF52840/DEC1: C405.1, U401.C1 (DEC1)
/400-nRF52840/DEC2: C413.1, U401.A18 (DEC2)
/400-nRF52840/DEC3: C411.1, U401.D23 (DEC3)
/400-nRF52840/DEC4_6: C410.1, C415.1, C416.1, L403.2, U401.B5 (DEC4), U401.E24 (DEC6)
/400-nRF52840/DEC5: C409.1, U401.N24 (DEC5)
/400-nRF52840/DECUSB: C420.1, U401.AC5 (DECUSB)
/400-nRF52840/NFC1: J401.1, U401.L24 (NFC1/P0.09)
/400-nRF52840/NFC2: J402.1, U401.J24 (NFC2/P0.10)
/400-nRF52840/XC1: C401.1, U401.B24 (XC1), Y401.1
/400-nRF52840/XC2: C402.1, U401.A23 (XC2), Y401.3
GND: C401.2, C402.2, C403.2, C404.2, C405.2, C406.2, C407.2, C408.2, C409.2, C410.2, C411.2, C412.2, C413.2, C414.2, C415.2, C416.2, C420.2, C421.2, C461.2, J2.2 (gnd), SW461.2, U401.B7 (VSS), U401.EP (VSS), U401.F23 (VSS_PA), Y401.2, Y401.4; also elsewhere on the board
P5: U401.L1 (P0.06); also elsewhere on the board
P7: U401.M2 (TRACECLK/P0.07); also elsewhere on the board
P9: U401.N1 (P0.08); also elsewhere on the board
P11: U401.P2 (P1.08); also elsewhere on the board
P13: U401.D2 (XL1/P0.00); also elsewhere on the board
P15: U401.F2 (XL2/P0.01); also elsewhere on the board
P17: U401.B9 (AIN6/P0.30); also elsewhere on the board
P19: U401.J1 (AIN2/P0.04); also elsewhere on the board
P21: U401.K2 (AIN3/P0.05); also elsewhere on the board
P23: U401.A20 (P1.10); also elsewhere on the board
P25: U401.A10 (AIN5/P0.29); also elsewhere on the board
P27: U401.A8 (AIN7/P0.31); also elsewhere on the board
P29: U401.A16 (P1.13); also elsewhere on the board
P30: U401.G1 (P0.26); also elsewhere on the board
P31: U401.U24 (P1.04); also elsewhere on the board
P32: U401.H2 (P0.27); also elsewhere on the board
P33: U401.A14 (P1.15); also elsewhere on the board
P34: U401.AC9 (P0.14); also elsewhere on the board
P35: U401.U1 (TRACEDATA1/P0.12); also elsewhere on the board
P36: U401.AD10 (P0.15); also elsewhere on the board
P37: U401.T2 (TRACEDATA2/P0.11); also elsewhere on the board
P38: U401.AC11 (P0.16); also elsewhere on the board
P39: U401.R1 (TRACEDATA3/P1.09); also elsewhere on the board
P40: U401.AD12 (P0.17); also elsewhere on the board
P42: U401.AD20 (P0.24); also elsewhere on the board
P44: U401.AC21 (P0.25); also elsewhere on the board
P46: U401.Y23 (P1.01); also elsewhere on the board
P52: U401.W24 (P1.02); also elsewhere on the board
SPI0: U401.AD22 (TRACEDATA0/P1.00); also elsewhere on the board
SPI1: U401.AD18 (P0.22); also elsewhere on the board
SPI2: U401.AC15 (P0.19); also elsewhere on the board
SPI4: U401.AC19 (P0.23); also elsewhere on the board
SPI5: U401.AC17 (P0.21); also elsewhere on the board
SPI7: U401.AD16 (P0.20); also elsewhere on the board

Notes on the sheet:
VDD_nRF has to be 3V3 for VDDIO
I2C
ADC
AD23
QSPI
Reset
A22
400-nRF52840
50mA
W1/Y2
AD14
QIAA config 5

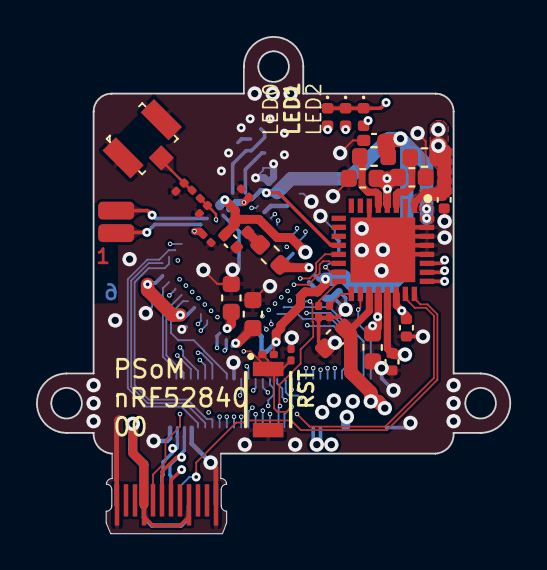
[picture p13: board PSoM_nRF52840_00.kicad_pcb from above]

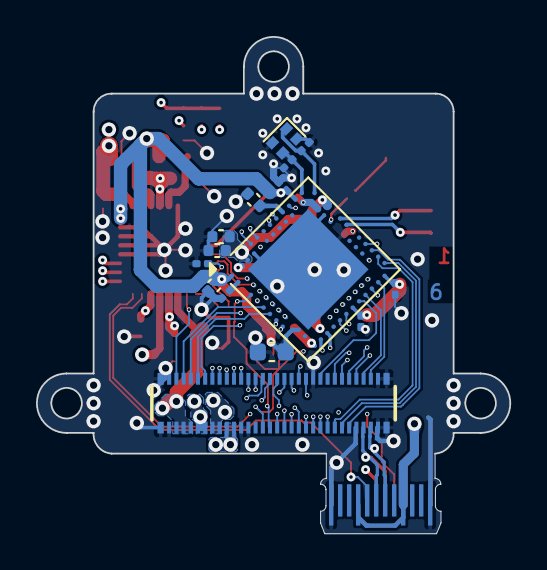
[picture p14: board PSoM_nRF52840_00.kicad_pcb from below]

Board: 6 copper layers, 26.3 x 27.6 mm, 48 parts (15 on the bottom side), 71 nets.

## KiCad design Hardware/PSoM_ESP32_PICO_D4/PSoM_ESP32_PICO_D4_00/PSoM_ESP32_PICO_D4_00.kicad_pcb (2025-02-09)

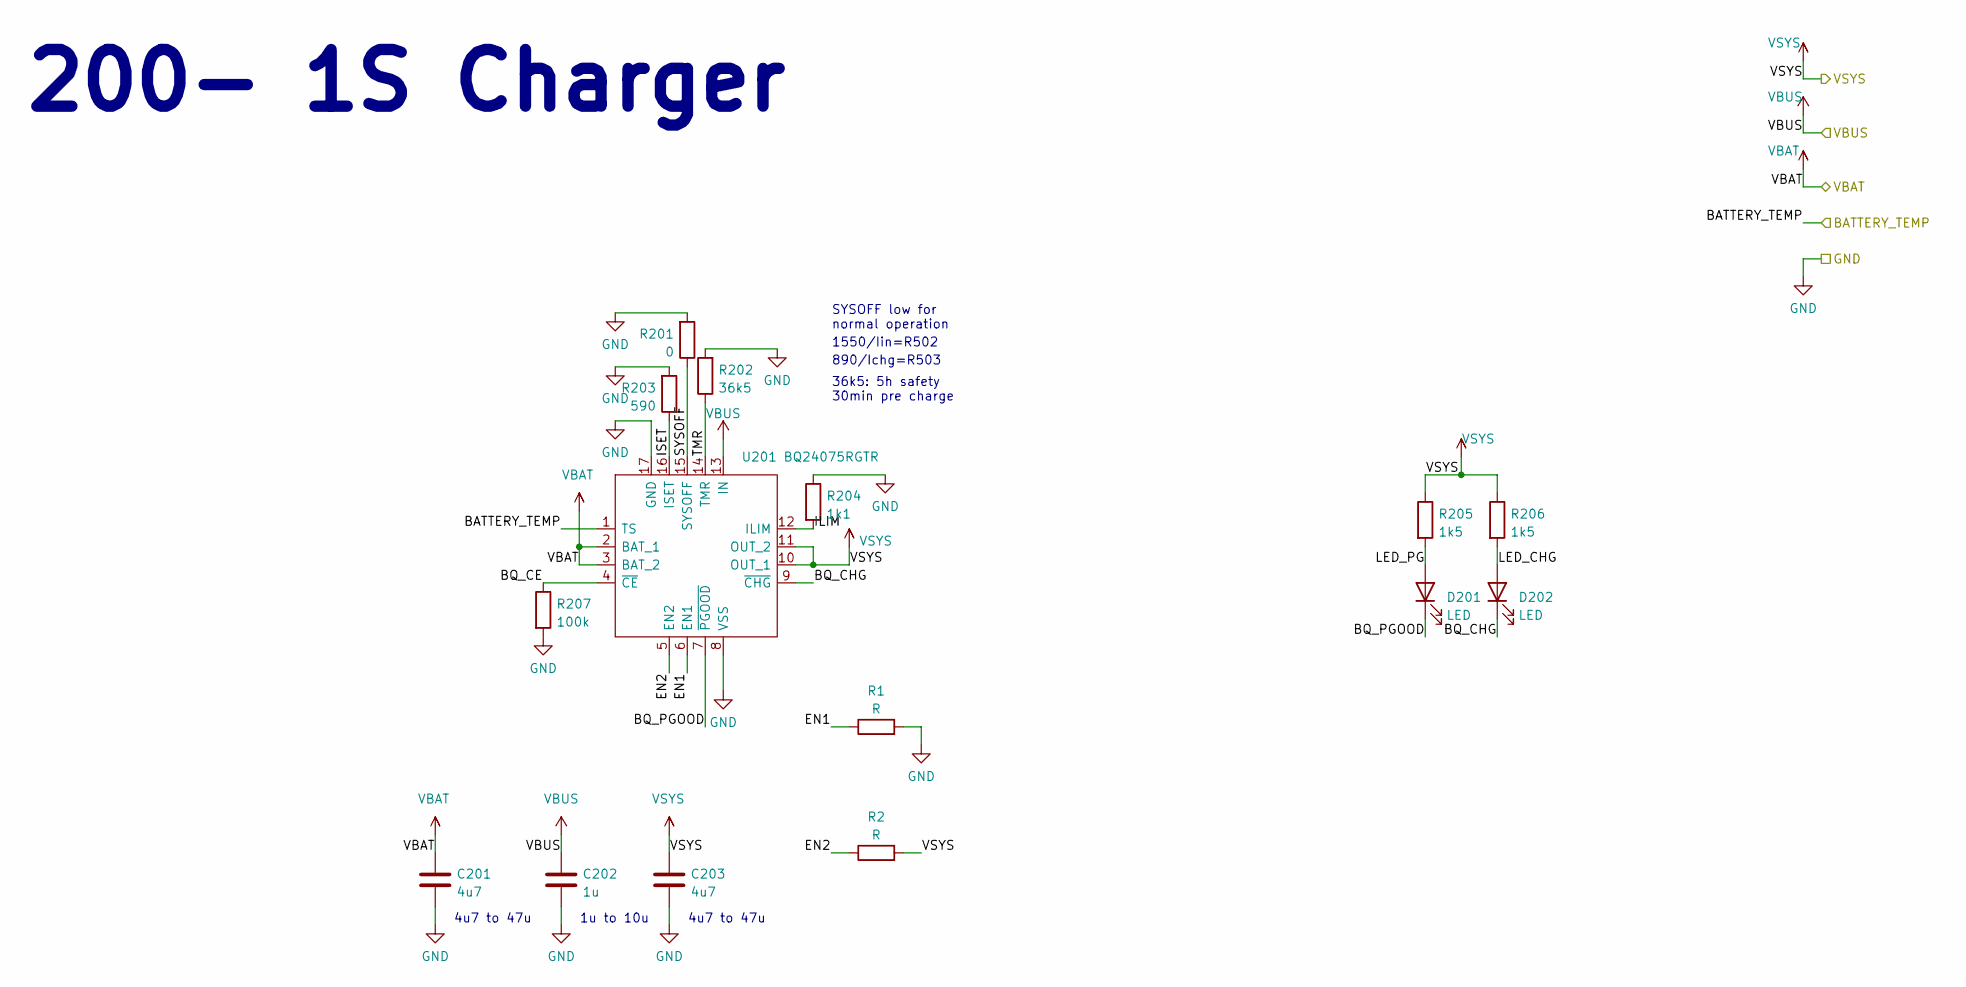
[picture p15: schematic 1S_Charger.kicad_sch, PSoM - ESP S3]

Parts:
C201, C203: 4u7; C_0603_1608Metric
C202: 1u; C_0603_1608Metric
D201, D202: LED; LED_0402_1005Metric
R1, R2: R; R_0402_1005Metric
R201: 0; R_0402_1005Metric
R202: 36k5; R_0402_1005Metric
R203: 590; R_0402_1005Metric
R204: 1k1; R_0402_1005Metric
R205, R206: 1k5; R_0402_1005Metric
R207: 100k; R_0402_1005Metric
U201: BQ24075RGTR; QFN50P300X300X100-17N-D; Mouser Part Number 595-BQ24075RGTR

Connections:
/100_Connectors/BATTERY_TEMP: U201.1 (TS); also elsewhere on the board
/200_1S_Charger/BQ_CE: R207.1, U201.4 (~CE)
/200_1S_Charger/BQ_CHG: D202.1 (K), U201.9 (~CHG)
/200_1S_Charger/BQ_PGOOD: D201.1 (K), U201.7 (~PGOOD)
/200_1S_Charger/EN1: R1.1, U201.6 (EN1)
/200_1S_Charger/EN2: R2.1, U201.5 (EN2)
/200_1S_Charger/ILIM: R204.2, U201.12 (ILIM)
/200_1S_Charger/ISET: R203.1, U201.16 (ISET)
/200_1S_Charger/LED_CHG: D202.2 (A), R206.2
/200_1S_Charger/LED_PG: D201.2 (A), R205.2
/200_1S_Charger/SYSOFF: R201.1, U201.15 (SYSOFF)
/200_1S_Charger/TMR: R202.1, U201.14 (TMR)
/VBAT: C201.1, U201.2 (BAT_1), U201.3 (BAT_2); also elsewhere on the board
/VSYS: C203.1, R2.2, R205.1, R206.1, U201.10 (OUT_1), U201.11 (OUT_2); also elsewhere on the board
GND: C201.2, C202.2, C203.2, R1.2, R201.2, R202.2, R203.2, R204.1, R207.2, U201.8 (VSS), U201.17 (GND); also elsewhere on the board
VBUS: C202.1, U201.13 (IN); also elsewhere on the board

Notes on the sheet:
890/Ichg=R503
200- 1S Charger
4u7 to 47u
1u to 10u
SYSOFF low for normal operation
36k5: 5h safety 30min pre charge
1550/Iin=R502

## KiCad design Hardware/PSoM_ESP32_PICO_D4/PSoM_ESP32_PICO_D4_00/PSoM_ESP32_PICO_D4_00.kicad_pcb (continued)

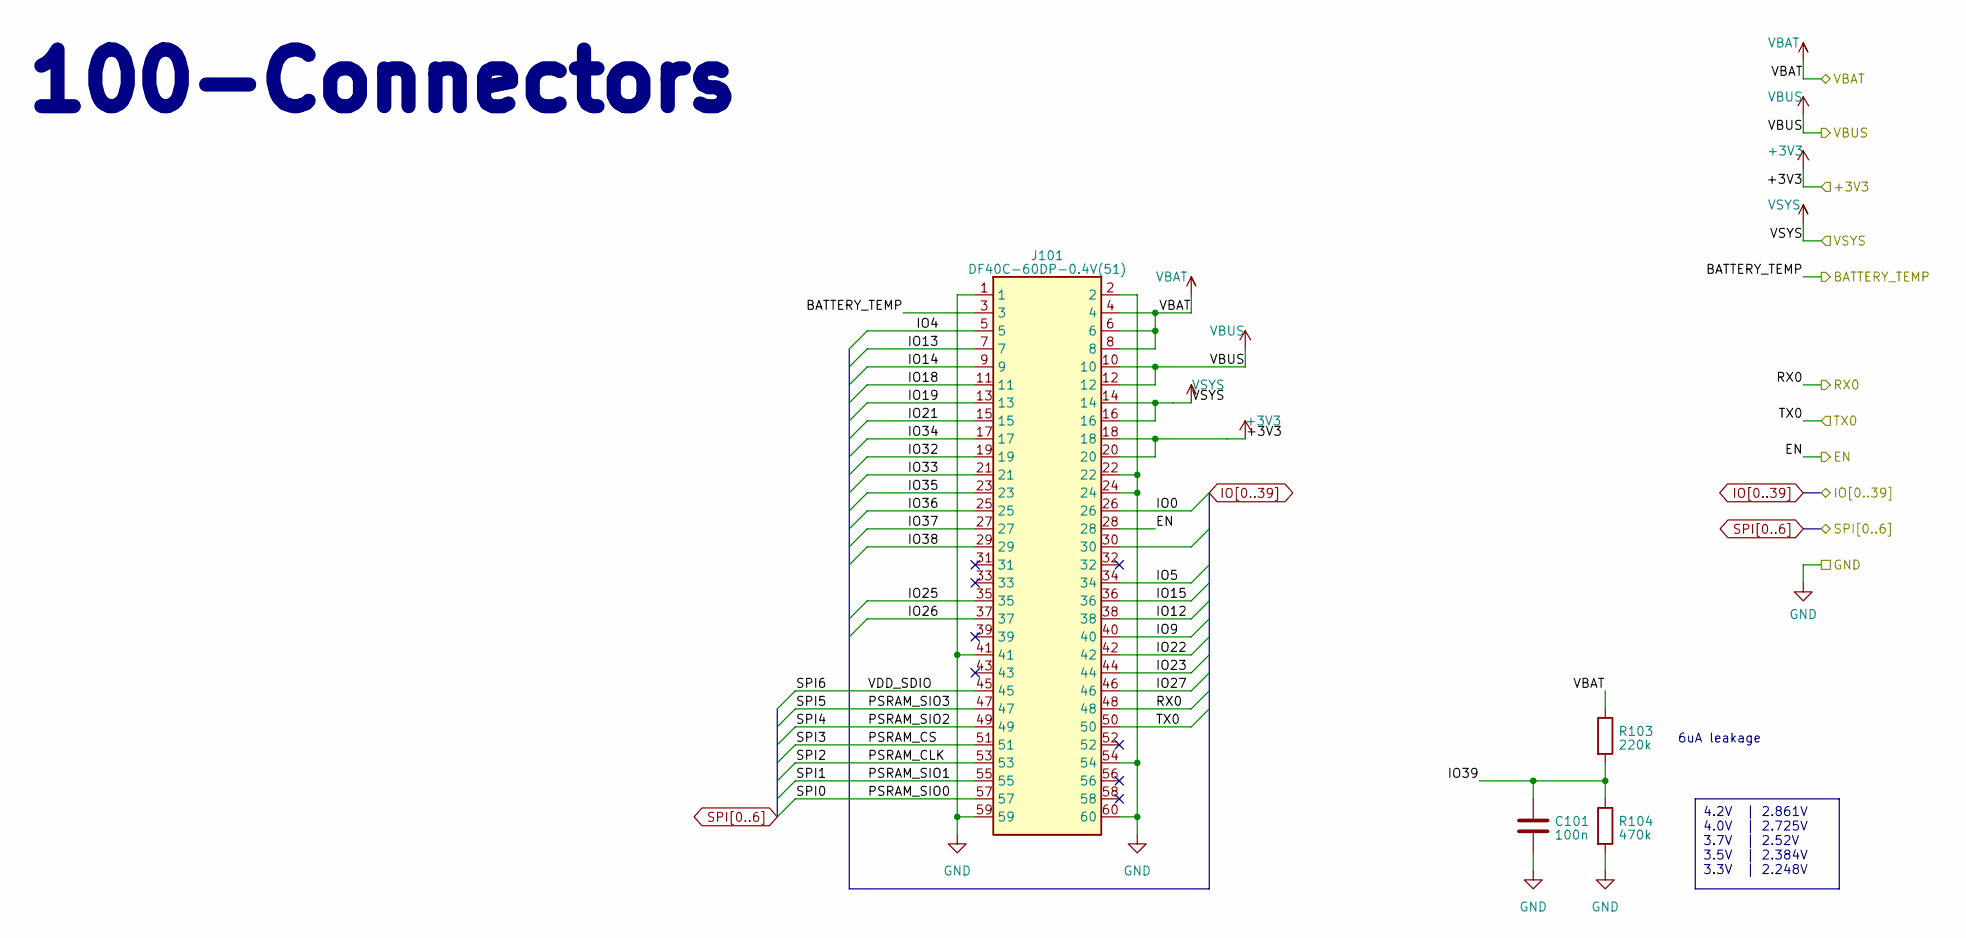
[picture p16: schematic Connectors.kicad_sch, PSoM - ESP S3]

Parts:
C101: 100n; C_0201_0603Metric
J101: DF40C-60DP-0.4V(51)
R103: 220k; R_0201_0603Metric
R104: 470k; R_0201_0603Metric

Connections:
+3V3: J101.18, J101.20; also elsewhere on the board
/100_Connectors/BATTERY_TEMP: J101.3; also elsewhere on the board
/100_Connectors/EN: J101.28; also elsewhere on the board
/100_Connectors/RX0: J101.48; also elsewhere on the board
/100_Connectors/TX0: J101.50; also elsewhere on the board
/VBAT: J101.4, J101.6, J101.8, R103.1; also elsewhere on the board
/VSYS: J101.14, J101.16; also elsewhere on the board
GND: C101.2, J101.1, J101.2, J101.22, J101.24, J101.41, J101.54, J101.59, J101.60, R104.2; also elsewhere on the board
IO0: J101.26; also elsewhere on the board
IO4: J101.5; also elsewhere on the board
IO5: J101.34; also elsewhere on the board
IO9: J101.40; also elsewhere on the board
IO12: J101.38; also elsewhere on the board
IO13: J101.7; also elsewhere on the board
IO14: J101.9; also elsewhere on the board
IO15: J101.36; also elsewhere on the board
IO18: J101.11; also elsewhere on the board
IO19: J101.13; also elsewhere on the board
IO21: J101.15; also elsewhere on the board
IO22: J101.42; also elsewhere on the board
IO23: J101.44; also elsewhere on the board
IO25: J101.35; also elsewhere on the board
IO26: J101.37; also elsewhere on the board
IO27: J101.46; also elsewhere on the board
IO32: J101.19; also elsewhere on the board
IO33: J101.21; also elsewhere on the board
IO34: J101.17; also elsewhere on the board
IO35: J101.23; also elsewhere on the board
IO36: J101.25; also elsewhere on the board
IO37: J101.27; also elsewhere on the board
IO38: J101.29; also elsewhere on the board
IO39: C101.1, R103.2, R104.1; also elsewhere on the board
SPI0: J101.57; also elsewhere on the board
SPI1: J101.55; also elsewhere on the board
SPI2: J101.53; also elsewhere on the board
SPI3: J101.51; also elsewhere on the board
SPI4: J101.49; also elsewhere on the board
SPI5: J101.47; also elsewhere on the board
SPI6: J101.45; also elsewhere on the board
VBUS: J101.10, J101.12; also elsewhere on the board

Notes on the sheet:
4.2V | 2.861V 4.0V | 2.725V 3.7V | 2.52V 3.5V | 2.384V 3.3V | 2.248V
100-Connectors
6uA leakage

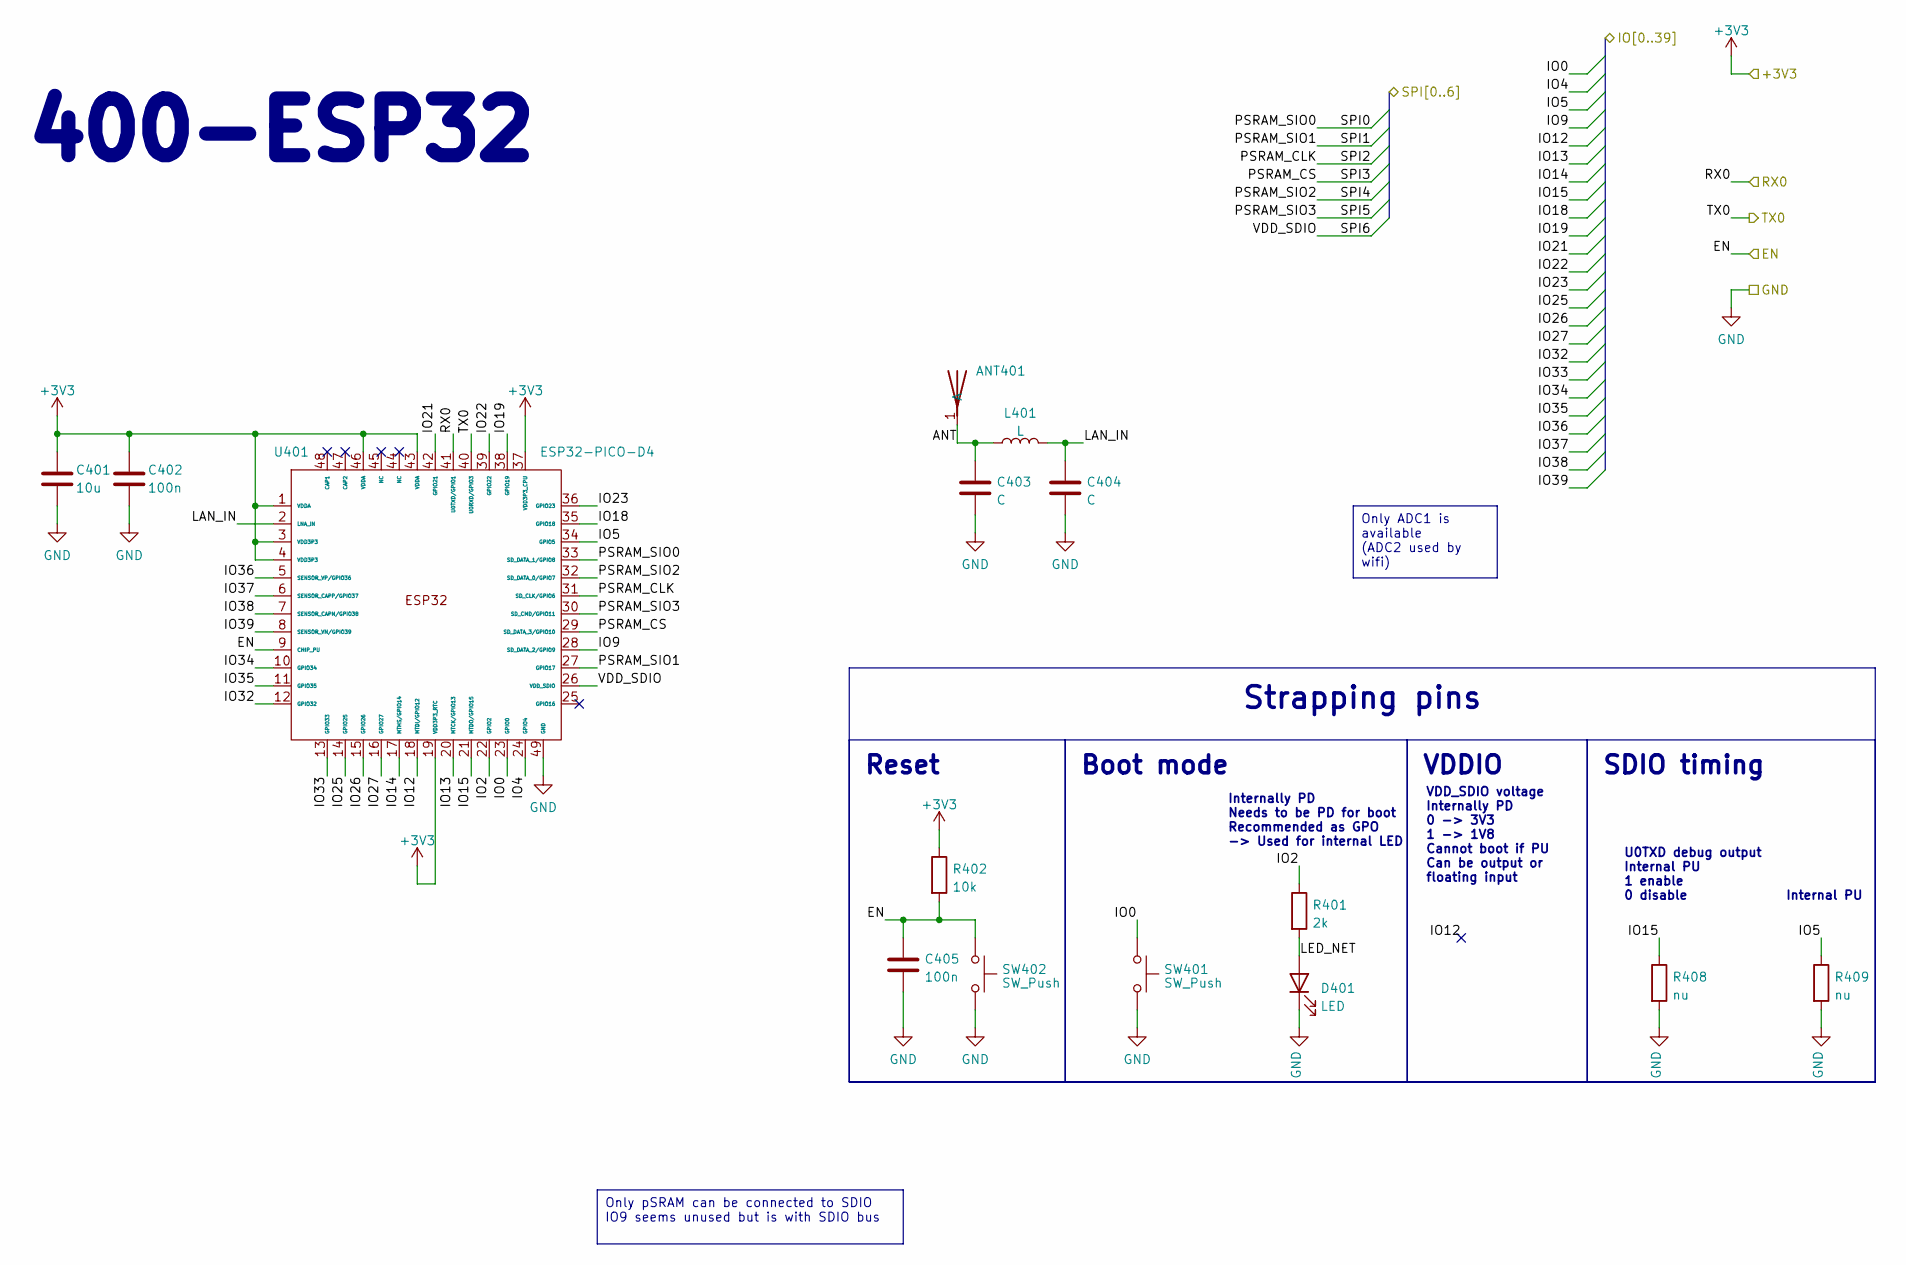
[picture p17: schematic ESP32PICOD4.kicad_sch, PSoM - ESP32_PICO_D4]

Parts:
ANT401: 2450AT18A100E; ANTC3216X140N; Mouser Part Number 609-2450AT18A100E
C401: 10u; C_0603_1608Metric
C402, C405: 100n; C_0201_0603Metric
C403, C404: C; C_0201_0603Metric
D401: LED; LED_0402_1005Metric
L401: L; L_0201_0603Metric
R401: 2k; R_0402_1005Metric
R402: 10k; R_0201_0603Metric
R408, R409: nu; R_0201_0603Metric
SW401, SW402: SW_Push; B3U-1000P
U401: ESP32-PICO-D4; ESP32-PICO-D4_1; Mouser Part Number 356-ESP32-PICO-D4

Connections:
+3V3: C401.1, C402.1, R402.1, U401.1 (VDDA), U401.3 (VDD3P3), U401.4 (VDD3P3), U401.19 (VDD3P3_RTC), U401.37 (VDD3P3_CPU), U401.43 (VDDA), U401.46 (VDDA); also elsewhere on the board
/100_Connectors/EN: C405.1, R402.2, SW402.1, U401.9 (CHIP_PU); also elsewhere on the board
/100_Connectors/RX0: U401.41 (U0TXD/GPIO1); also elsewhere on the board
/100_Connectors/TX0: U401.40 (U0RXD/GPIO3); also elsewhere on the board
/400_ESP32/ANT: ANT401.1 (A), C403.1, L401.1
/400_ESP32/LAN_IN: C404.1, L401.2, U401.2 (LNA_IN)
/400_ESP32/LED_NET: D401.2 (A), R401.2
GND: C401.2, C402.2, C403.2, C404.2, C405.2, D401.1 (K), R408.2, R409.2, SW401.2, SW402.2, U401.49 (GND); also elsewhere on the board
IO0: SW401.1, U401.23 (GPIO0); also elsewhere on the board
IO2: R401.1, U401.22 (GPIO2)
IO4: U401.24 (GPIO4); also elsewhere on the board
IO5: R409.1, U401.34 (GPIO5); also elsewhere on the board
IO9: U401.28 (SD_DATA_2/GPIO9); also elsewhere on the board
IO12: U401.18 (MTDI/GPIO12); also elsewhere on the board
IO13: U401.20 (MTCK/GPIO13); also elsewhere on the board
IO14: U401.17 (MTMS/GPIO14); also elsewhere on the board
IO15: R408.1, U401.21 (MTDO/GPIO15); also elsewhere on the board
IO18: U401.35 (GPIO18); also elsewhere on the board
IO19: U401.38 (GPIO19); also elsewhere on the board
IO21: U401.42 (GPIO21); also elsewhere on the board
IO22: U401.39 (GPIO22); also elsewhere on the board
IO23: U401.36 (GPIO23); also elsewhere on the board
IO25: U401.14 (GPIO25); also elsewhere on the board
IO26: U401.15 (GPIO26); also elsewhere on the board
IO27: U401.16 (GPIO27); also elsewhere on the board
IO32: U401.12 (GPIO32); also elsewhere on the board
IO33: U401.13 (GPIO33); also elsewhere on the board
IO34: U401.10 (GPIO34); also elsewhere on the board
IO35: U401.11 (GPIO35); also elsewhere on the board
IO36: U401.5 (SENSOR_VP/GPIO36); also elsewhere on the board
IO37: U401.6 (SENSOR_CAPP/GPIO37); also elsewhere on the board
IO38: U401.7 (SENSOR_CAPN/GPIO38); also elsewhere on the board
IO39: U401.8 (SENSOR_VN/GPIO39); also elsewhere on the board
SPI0: U401.33 (SD_DATA_1/GPIO8); also elsewhere on the board
SPI1: U401.27 (GPIO17); also elsewhere on the board
SPI2: U401.31 (SD_CLK/GPIO6); also elsewhere on the board
SPI3: U401.29 (SD_DATA_3/GPIO10); also elsewhere on the board
SPI4: U401.32 (SD_DATA_0/GPIO7); also elsewhere on the board
SPI5: U401.30 (SD_CMD/GPIO11); also elsewhere on the board
SPI6: U401.26 (VDD_SDIO); also elsewhere on the board

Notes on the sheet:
Only pSRAM can be connected to SDIO IO9 seems unused but is with SDIO bus
Reset
SDIO timing
VDDIO
Boot mode
Strapping pins
Only ADC1 is available (ADC2 used by wifi)
Internally PD Needs to be PD for boot Recommended as GPO -> Used for internal LED
Internal PU
400-ESP32
VDD_SDIO voltage Internally PD 0 -> 3V3 1 -> 1V8 Cannot boot if PU Can be output or floating input
U0TXD debug output Internal PU 1 enable 0 disable

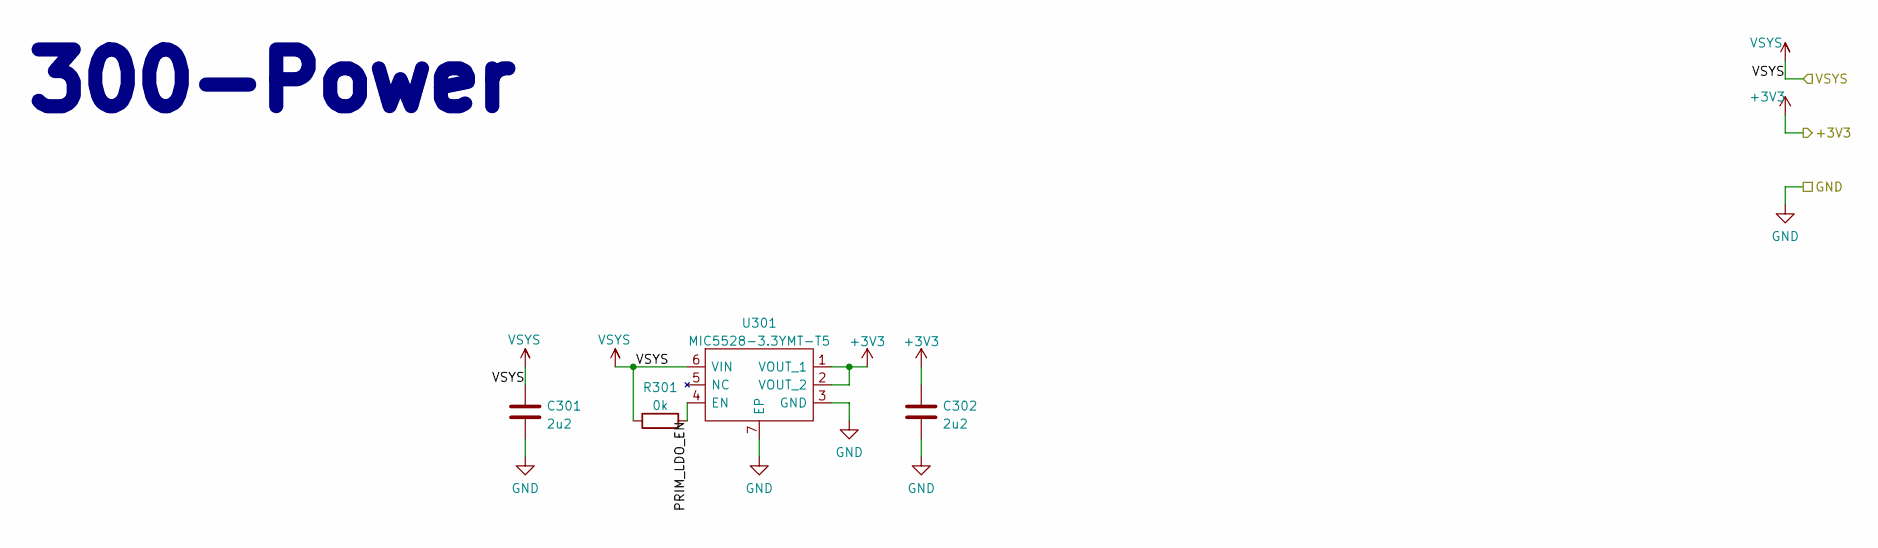
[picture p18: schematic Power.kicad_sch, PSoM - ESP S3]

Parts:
C301, C302: 2u2; C_0603_1608Metric
R301: 0k; R_0201_0603Metric
U301: MIC5528-3.3YMT-T5; SON40P120X120X60-7N-D; Mouser Part Number 998-MIC5528-3.3YMTT5

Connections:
+3V3: C302.1, U301.1 (VOUT_1), U301.2 (VOUT_2); also elsewhere on the board
/300_Power/PRIM_LDO_EN: R301.2, U301.4 (EN)
/VSYS: C301.1, R301.1, U301.6 (VIN); also elsewhere on the board
GND: C301.2, C302.2, U301.3 (GND), U301.7 (EP); also elsewhere on the board

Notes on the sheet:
300-Power

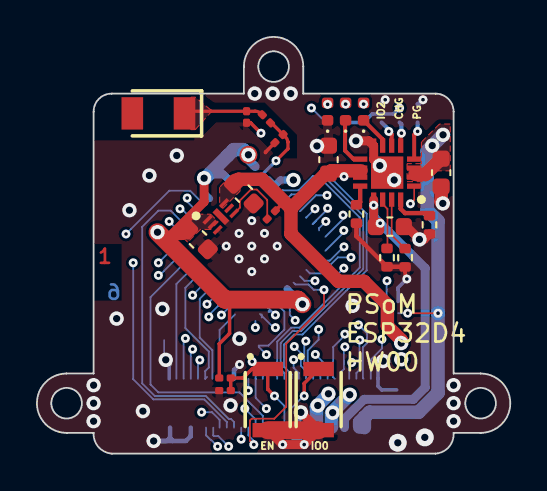
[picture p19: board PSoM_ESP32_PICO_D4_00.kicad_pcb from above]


Board: 6 copper layers, 26.3 x 23.2 mm, 38 parts (15 on the bottom side), 56 nets.

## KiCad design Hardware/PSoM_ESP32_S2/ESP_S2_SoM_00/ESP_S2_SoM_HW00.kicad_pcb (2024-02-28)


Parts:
C201, C203: 4u7; C_0603_1608Metric
C202: 1u; C_0603_1608Metric
D201, D202: LED; LED_0402_1005Metric
R1, R2: R; R_0402_1005Metric
R201: 0; R_0402_1005Metric
R202: 36k5; R_0402_1005Metric
R203: 590; R_0402_1005Metric
R204: 1k1; R_0402_1005Metric
R205, R206: 1k5; R_0402_1005Metric
R207: 100k; R_0402_1005Metric
U201: BQ24075RGTR; QFN50P300X300X100-17N-D; Mouser Part Number 595-BQ24075RGTR

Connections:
/100_Connectors/BATTERY_TEMP: U201.1 (TS); also elsewhere on the board
/200_1S_Charger/BQ_CE: R207.1, U201.4 (~CE)
/200_1S_Charger/BQ_CHG: D202.1 (K), U201.9 (~CHG)
/200_1S_Charger/BQ_PGOOD: D201.1 (K), U201.7 (~PGOOD)
/200_1S_Charger/EN1: R1.1, U201.6 (EN1)
/200_1S_Charger/EN2: R2.1, U201.5 (EN2)
/200_1S_Charger/ILIM: R204.2, U201.12 (ILIM)
/200_1S_Charger/ISET: R203.1, U201.16 (ISET)
/200_1S_Charger/LED_CHG: D202.2 (A), R206.2
/200_1S_Charger/LED_PG: D201.2 (A), R205.2
/200_1S_Charger/SYSOFF: R201.1, U201.15 (SYSOFF)
/200_1S_Charger/TMR: R202.1, U201.14 (TMR)
/VBAT: C201.1, U201.2 (BAT_1), U201.3 (BAT_2); also elsewhere on the board
/VSYS: C203.1, R2.2, R205.1, R206.1, U201.10 (OUT_1), U201.11 (OUT_2); also elsewhere on the board
GND: C201.2, C202.2, C203.2, R1.2, R201.2, R202.2, R203.2, R204.1, R207.2, U201.8 (VSS), U201.17 (GND); also elsewhere on the board
VBUS: C202.1, U201.13 (IN); also elsewhere on the board

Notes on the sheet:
890/Ichg=R503
200- 1S Charger
4u7 to 47u
1u to 10u
SYSOFF low for normal operation
36k5: 5h safety 30min pre charge
1550/Iin=R502


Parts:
C415: 100n; C_0201_0603Metric
J101: DF40C-60DP-0.4V(51)
J102: Bare PCB USB C; usb-c-pcb; Mouser Part Number 640-USB4510031A
R101, R102: 5.1k; R_0201_0603Metric
R103: 220k; R_0201_0603Metric
R104: 470k; R_0201_0603Metric

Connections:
/100_Connectors/BATTERY_TEMP: J101.3; also elsewhere on the board
/100_Connectors/CC1: J102.A5 (CC1), R102.1
/100_Connectors/CC2: J102.B5 (CC2), R101.1
/100_Connectors/D+: J101.56, J102.A6 (D+), J102.B6 (D+); also elsewhere on the board
/100_Connectors/D-: J101.58, J102.A7 (D-), J102.B7 (D-); also elsewhere on the board
/100_Connectors/EN: J101.28; also elsewhere on the board
/100_Connectors/RX0: J101.48; also elsewhere on the board
/100_Connectors/TX0: J101.50; also elsewhere on the board
/VBAT: J101.4, J101.6, J101.8, R103.1; also elsewhere on the board
/VSYS: J101.14, J101.16; also elsewhere on the board
GND: C415.2, J101.1, J101.2, J101.22, J101.24, J101.41, J101.54, J101.59, J101.60, J102.A1 (GND), J102.A12 (GND), J102.B1 (GND), J102.B12 (GND), R101.2, R102.2, R104.2; also elsewhere on the board
IO0: J101.26; also elsewhere on the board
IO2: J101.5; also elsewhere on the board
IO3: J101.7; also elsewhere on the board
IO4: J101.9; also elsewhere on the board
IO5: J101.11; also elsewhere on the board
IO6: J101.13; also elsewhere on the board
IO7: J101.15; also elsewhere on the board
IO8: J101.17; also elsewhere on the board
IO9: J101.19; also elsewhere on the board
IO10: J101.21; also elsewhere on the board
IO11: J101.23; also elsewhere on the board
IO12: J101.25; also elsewhere on the board
IO13: J101.27; also elsewhere on the board
IO14: J101.29; also elsewhere on the board
IO15: J101.31; also elsewhere on the board
IO16: J101.33; also elsewhere on the board
IO17: J101.35; also elsewhere on the board
IO18: J101.37; also elsewhere on the board
IO21: J101.39; also elsewhere on the board
IO33: J101.30; also elsewhere on the board
IO34: J101.32; also elsewhere on the board
IO35: J101.34; also elsewhere on the board
IO36: J101.36; also elsewhere on the board
IO37: J101.38; also elsewhere on the board
IO38: J101.40; also elsewhere on the board
IO39: J101.44; also elsewhere on the board
IO40: J101.46; also elsewhere on the board
IO41: J101.42; also elsewhere on the board
IO42: J101.52; also elsewhere on the board
SPI0: J101.57; also elsewhere on the board
SPI1: J101.55; also elsewhere on the board
SPI2: J101.53; also elsewhere on the board
SPI3: J101.51; also elsewhere on the board
SPI4: J101.49; also elsewhere on the board
SPI5: J101.47; also elsewhere on the board
SPI6: J101.45; also elsewhere on the board
SPI7: J101.43; also elsewhere on the board
VBUS: J101.10, J101.12, J102.A4 (VBUS), J102.A9 (VBUS), J102.B4 (VBUS), J102.B9 (VBUS); also elsewhere on the board

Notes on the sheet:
4.2V | 2.861V 4.0V | 2.725V 3.7V | 2.52V 3.5V | 2.384V 3.3V | 2.248V
100-USB
6uA leakage


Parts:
ANT401: 2450AT18A100E; ANTC3216X140N; Mouser Part Number 609-2450AT18A100E
C401, C402: 15p; C_0201_0603Metric
C403, C404, C405, C408, C411, C412, C414, C415, C416: 100n; C_0201_0603Metric
C406, C407: C; C_0201_0603Metric
C409: 10u; C_0603_1608Metric
C410, C413: 1u; C_0402_1005Metric
D401: LED; LED_0402_1005Metric
L401: L; L_0201_0603Metric
R401: 0; R_0201_0603Metric
R402: 2k; R_0402_1005Metric
R403, R404: 10k; R_0201_0603Metric
R405, R406, R407, R408: nu; R_0201_0603Metric
SW401, SW402: SW_Push; B3U-1000P
U401: ESP32-S2FH4; QFN40P700X700X90-57N-D; Mouser Part Number 356-ESP32-S2FH4
Y601: Crystal_GND24_Small; Crystal_SMD_2016-4Pin_2.0x1.6mm

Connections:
/100_Connectors/D+: U401.26 (GPIO20); also elsewhere on the board
/100_Connectors/D-: U401.25 (GPIO19); also elsewhere on the board
/100_Connectors/EN: C414.1, R403.2, SW401.1, U401.56 (CHIP_PU); also elsewhere on the board
/100_Connectors/RX0: U401.49 (U0RXD); also elsewhere on the board
/100_Connectors/TX0: U401.48 (U0TXD); also elsewhere on the board
/400_ESP32/ANT: ANT401.1 (A), C406.1, L401.1
/400_ESP32/IO45: R406.2, R408.1, U401.50 (GPIO45)
/400_ESP32/IO46: R405.2, R407.1, U401.55 (GPIO46)
/400_ESP32/LED_NET: D401.2 (A), R402.2
/400_ESP32/LNA_IN: C407.1, L401.2, U401.2 (LNA_IN)
GND: C401.2, C402.2, C403.2, C404.2, C405.2, C406.2, C407.2, C408.2, C409.2, C410.2, C411.2, C412.2, C413.2, C414.2, C415.2, C416.2, D401.1 (K), R407.2, R408.2, SW401.2, SW402.2, U401.57 (GND), Y601.2, Y601.4; also elsewhere on the board
IO0: SW402.1, U401.5 (GPIO0); also elsewhere on the board
IO2: U401.7 (GPIO2); also elsewhere on the board
IO3: U401.8 (GPIO3); also elsewhere on the board
IO4: U401.9 (GPIO4); also elsewhere on the board
IO5: U401.10 (GPIO5); also elsewhere on the board
IO6: U401.11 (GPIO6); also elsewhere on the board
IO7: U401.12 (GPIO7); also elsewhere on the board
IO8: U401.13 (GPIO8); also elsewhere on the board
IO9: U401.14 (GPIO9); also elsewhere on the board
IO10: U401.15 (GPIO10); also elsewhere on the board
IO11: U401.16 (GPIO11); also elsewhere on the board
IO12: U401.17 (GPIO12); also elsewhere on the board
IO13: U401.18 (GPIO13); also elsewhere on the board
IO14: U401.19 (GPIO14); also elsewhere on the board
IO15: R402.1, U401.21 (XTAL_32K_P); also elsewhere on the board
IO16: U401.22 (XTAL_32K_N); also elsewhere on the board
IO17: U401.23 (DAC_1); also elsewhere on the board
IO18: R404.2, U401.24 (DAC_2); also elsewhere on the board
IO21: U401.28 (GPIO21); also elsewhere on the board
IO33: U401.37 (GPIO33); also elsewhere on the board
IO34: U401.38 (GPIO34); also elsewhere on the board
IO35: U401.39 (GPIO35); also elsewhere on the board
IO36: U401.40 (GPIO36); also elsewhere on the board
IO37: U401.41 (GPIO37); also elsewhere on the board
IO38: U401.42 (GPIO38); also elsewhere on the board
IO39: U401.43 (MTCK); also elsewhere on the board
IO40: U401.44 (MTD0); also elsewhere on the board
IO41: U401.46 (MTDI); also elsewhere on the board
IO42: U401.47 (MTMS); also elsewhere on the board
unnamed: C401.1, R401.1, Y601.3
unnamed: C402.1, U401.52 (XTAL_N), Y601.1
unnamed: R401.2, U401.53 (XTAL_P)
SPI0: U401.36 (SPID); also elsewhere on the board
SPI1: U401.35 (SPIQ); also elsewhere on the board
SPI2: U401.34 (SPICLK); also elsewhere on the board
SPI3: U401.33 (SPICS0); also elsewhere on the board
SPI4: U401.32 (SPIWP); also elsewhere on the board
SPI5: U401.31 (SPIHD); also elsewhere on the board
SPI6: C412.1, C413.1, U401.30 (VDD_SPI); also elsewhere on the board
SPI7: U401.29 (SPICS1); also elsewhere on the board

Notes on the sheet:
Boot mode
Reset
40MHz 10ppm
400-ESP32
Strapping pins


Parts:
C301, C302: 2u2; C_0603_1608Metric
R301: 0k; R_0201_0603Metric
U301: MIC5528-3.3YMT-T5; SON40P120X120X60-7N-D; Mouser Part Number 998-MIC5528-3.3YMTT5

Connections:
/300_Power/PRIM_LDO_EN: R301.2, U301.4 (EN)
/VSYS: C301.1, R301.1, U301.6 (VIN); also elsewhere on the board
GND: C301.2, C302.2, U301.3 (GND), U301.7 (EP); also elsewhere on the board

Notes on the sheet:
300-Power

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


Board: 6 copper layers, 26.3 x 27.6 mm, 57 parts (29 on the bottom side), 71 nets.

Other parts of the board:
C101: 100n; C_0201_0603Metric

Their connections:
GND: C101.2; also elsewhere on the board

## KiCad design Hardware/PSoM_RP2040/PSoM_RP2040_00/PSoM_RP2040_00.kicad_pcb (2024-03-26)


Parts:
C301, C303: 4u7; C_0603_1608Metric
C302: 1u; C_0603_1608Metric
D301, D302: LED; LED_0402_1005Metric
R301: 100k; R_0402_1005Metric
R302: 590; R_0402_1005Metric
R303: 0; R_0402_1005Metric
R304: 36k5; R_0402_1005Metric
R305: 1k1; R_0402_1005Metric
R306, R307: R; R_0402_1005Metric
R308, R309: 1k5; R_0402_1005Metric
U301: BQ24075RGTR; QFN50P300X300X100-17N-D; Mouser Part Number 595-BQ24075RGTR

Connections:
/200_Connectors/BATTERY_TEMP: U301.1 (TS); also elsewhere on the board
/300_1S_Charger/BQ_CE: R301.1, U301.4 (~CE)
/300_1S_Charger/BQ_CHG: D302.1 (K), U301.9 (~CHG)
/300_1S_Charger/BQ_PGOOD: D301.1 (K), U301.7 (~PGOOD)
/300_1S_Charger/EN1: R306.1, U301.6 (EN1)
/300_1S_Charger/EN2: R307.1, U301.5 (EN2)
/300_1S_Charger/ILIM: R305.2, U301.12 (ILIM)
/300_1S_Charger/ISET: R302.1, U301.16 (ISET)
/300_1S_Charger/LED_CHG: D302.2 (A), R309.2
/300_1S_Charger/LED_PG: D301.2 (A), R308.2
/300_1S_Charger/SYSOFF: R303.1, U301.15 (SYSOFF)
/300_1S_Charger/TMR: R304.1, U301.14 (TMR)
/VBAT: C301.1, U301.2 (BAT_1), U301.3 (BAT_2); also elsewhere on the board
/VSYS: C303.1, R307.2, R308.1, R309.1, U301.10 (OUT_1), U301.11 (OUT_2); also elsewhere on the board
VBUS: C302.1, U301.13 (IN); also elsewhere on the board

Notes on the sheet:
890/Ichg=R503
300- 1S Charger
4u7 to 47u
1u to 10u
SYSOFF low for normal operation
36k5: 5h safety 30min pre charge
1550/Iin=R502


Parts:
C415: 100n; C_0201_0603Metric
J201: Bare PCB USB C; usb-c-pcb; Mouser Part Number 640-USB4510031A
J202: DF40C-60DP-0.4V(51)
R201, R202: 5.1k; R_0201_0603Metric
R203: 220k; R_0201_0603Metric
R204: 0; R_0201_0603Metric
R205: 470k; R_0201_0603Metric

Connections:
+3V3: J202.18, J202.20, J202.45; also elsewhere on the board
/200_Connectors/BATTERY_TEMP: J202.3; also elsewhere on the board
/200_Connectors/CC1: J201.A5 (CC1), R202.1
/200_Connectors/CC2: J201.B5 (CC2), R201.1
/200_Connectors/D+: J201.A6 (D+), J201.B6 (D+), J202.56; also elsewhere on the board
/200_Connectors/D-: J201.A7 (D-), J201.B7 (D-), J202.58; also elsewhere on the board
/200_Connectors/EN: J202.28; also elsewhere on the board
/200_Connectors/SWCLK: J202.50; also elsewhere on the board
/200_Connectors/SWD: J202.48; also elsewhere on the board
/VBAT: J202.4, J202.6, J202.8, R203.1; also elsewhere on the board
/VSYS: J202.14, J202.16; also elsewhere on the board
IO0: J202.5; also elsewhere on the board
IO1: J202.7; also elsewhere on the board
IO2: J202.9; also elsewhere on the board
IO3: J202.11; also elsewhere on the board
IO4: J202.13; also elsewhere on the board
IO5: J202.15; also elsewhere on the board
IO6: J202.17; also elsewhere on the board
IO7: J202.19; also elsewhere on the board
IO8: J202.21; also elsewhere on the board
IO9: J202.23; also elsewhere on the board
IO10: J202.25; also elsewhere on the board
IO11: J202.27; also elsewhere on the board
IO12: J202.29; also elsewhere on the board
IO13: J202.31; also elsewhere on the board
IO14: J202.33; also elsewhere on the board
IO15: J202.35; also elsewhere on the board
IO16: J202.37; also elsewhere on the board
IO17: J202.39; also elsewhere on the board
IO18: J202.43; also elsewhere on the board
IO19: J202.26; also elsewhere on the board
IO20: J202.30; also elsewhere on the board
IO21: J202.32; also elsewhere on the board
IO22: J202.34; also elsewhere on the board
IO23: J202.36; also elsewhere on the board
IO24: J202.38; also elsewhere on the board
IO25: J202.40; also elsewhere on the board
IO26: J202.42; also elsewhere on the board
IO27: J202.44; also elsewhere on the board
IO28: J202.46; also elsewhere on the board
SPI0: J202.57; also elsewhere on the board
SPI1: J202.55; also elsewhere on the board
SPI2: J202.53; also elsewhere on the board
SPI3: J202.51; also elsewhere on the board
SPI4: J202.49; also elsewhere on the board
SPI5: J202.47; also elsewhere on the board
VBUS: J201.A4 (VBUS), J201.A9 (VBUS), J201.B4 (VBUS), J201.B9 (VBUS), J202.10, J202.12; also elsewhere on the board

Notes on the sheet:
4.2V | 2.861V 4.0V | 2.725V 3.7V | 2.52V 3.5V | 2.384V 3.3V | 2.248V
200- Connectors
6uA leakage


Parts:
C501, C502, C504, C505, C507, C508, C509, C510, C513: 100n; C_0201_0603Metric
C503, C506: 1u; C_0402_1005Metric
C511, C512: 15p; C_0201_0603Metric
D501: LED; LED_0402_1005Metric
R501, R502: 27; R_0201_0603Metric
R503, R505: 1k; R_0201_0603Metric
R504: nu; R_0201_0603Metric
R506: 2k; R_0402_1005Metric
R507: 10k; R_0201_0603Metric
SW501, SW502: SW_Push; B3U-1000P
U501: SC0914_7_; QFN40P700X700X90-57N-D; Mouser Part Number 358-SC09147
U502: W25Q128JVPIQ_TR; SON127P600X500X80-9N-D; Mouser Part Number 454-W25Q128JVPIQTR
Y501: 830105420809; Mouser Part Number 710-830105420809

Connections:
+1V1: C501.1, C502.1, C503.1, U501.23 (DVDD), U501.45 (VREG_VOUT), U501.50 (DVDD)
+3V3: C504.1, C505.1, C506.1, C507.1, C508.1, C509.1, C510.1, C513.1, R504.1, R507.1, U501.1 (IOVDD), U501.10 (IOVDD), U501.22 (IOVDD), U501.33 (IOVDD), U501.42 (IOVDD), U501.43 (ADC_AVDD), U501.44 (VREG_IN), U501.48 (USB_VDD), U501.49 (IOVDD), U502.8 (VCC); also elsewhere on the board
/200_Connectors/BOOT0: R503.2, R507.2, SW501.1
/200_Connectors/D+: R502.1; also elsewhere on the board
/200_Connectors/D-: R501.1; also elsewhere on the board
/200_Connectors/EN: SW502.1, U501.26 (RUN); also elsewhere on the board
/200_Connectors/SWCLK: U501.24 (SWCLK); also elsewhere on the board
/200_Connectors/SWD: U501.25 (SWD); also elsewhere on the board
/500_RP2040/DM: R501.2, U501.46 (USB_DM)
/500_RP2040/DP: R502.2, U501.47 (USB_DP)
/500_RP2040/LED_NET: D501.2 (A), R506.2
/500_RP2040/XIN: C512.1, U501.20 (XIN), Y501.3
/500_RP2040/XOUT: R505.2, U501.21 (XOUT)
IO0: U501.2 (GPIO0); also elsewhere on the board
IO1: U501.3 (GPIO1); also elsewhere on the board
IO2: U501.4 (GPIO2); also elsewhere on the board
IO3: U501.5 (GPIO3); also elsewhere on the board
IO4: U501.6 (GPIO4); also elsewhere on the board
IO5: U501.7 (GPIO5); also elsewhere on the board
IO6: U501.8 (GPIO6); also elsewhere on the board
IO7: U501.9 (GPIO7); also elsewhere on the board
IO8: U501.11 (GPIO8); also elsewhere on the board
IO9: U501.12 (GPIO9); also elsewhere on the board
IO10: U501.13 (GPIO10); also elsewhere on the board
IO11: U501.14 (GPIO11); also elsewhere on the board
IO12: U501.15 (GPIO12); also elsewhere on the board
IO13: U501.16 (GPIO13); also elsewhere on the board
IO14: U501.17 (GPIO14); also elsewhere on the board
IO15: R506.1, U501.18 (GPIO15); also elsewhere on the board
IO16: U501.27 (GPIO16); also elsewhere on the board
IO17: U501.28 (GPIO17); also elsewhere on the board
IO18: U501.29 (GPIO18); also elsewhere on the board
IO19: U501.30 (GPIO19); also elsewhere on the board
IO20: U501.31 (GPIO20); also elsewhere on the board
IO21: U501.32 (GPIO21); also elsewhere on the board
IO22: U501.34 (GPIO22); also elsewhere on the board
IO23: U501.35 (GPIO23); also elsewhere on the board
IO24: U501.36 (GPIO24); also elsewhere on the board
IO25: U501.37 (GPIO25); also elsewhere on the board
IO26: U501.38 (GPIO26_ADC0); also elsewhere on the board
IO27: U501.39 (GPIO27_ADC1); also elsewhere on the board
IO28: U501.40 (GPIO28_ADC2); also elsewhere on the board
unnamed: C511.1, R505.1, Y501.1
SPI0: U501.53 (QSPI_SD0), U502.5 (DI_(IO0)); also elsewhere on the board
SPI1: U501.55 (QSPI_SD1), U502.2 (DO_(IO1)); also elsewhere on the board
SPI2: U501.52 (QSPI_SCLK), U502.6 (CLK); also elsewhere on the board
SPI3: R503.1, R504.2, U501.56 (QSPI_SS), U502.1 (~CS); also elsewhere on the board
SPI4: U501.54 (QSPI_SD2), U502.3 (~WP_(IO2)); also elsewhere on the board
SPI5: U501.51 (QSPI_SD3), U502.7 (~HOLD_OR_RESET_(IO3)); also elsewhere on the board

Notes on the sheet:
500-RP2040
Strapping pins


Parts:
C401, C402: 2u2; C_0603_1608Metric
R401: 0k; R_0201_0603Metric
U401: MIC5528-3.3YMT-T5; SON40P120X120X60-7N-D; Mouser Part Number 998-MIC5528-3.3YMTT5

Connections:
+3V3: C402.1, U401.1 (VOUT_1), U401.2 (VOUT_2); also elsewhere on the board
/400_Power/PRIM_LDO_EN: R401.2, U401.4 (EN)
/VSYS: C401.1, R401.1, U401.6 (VIN); also elsewhere on the board

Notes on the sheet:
400-Power

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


Board: 6 copper layers, 26.3 x 27.6 mm, 53 parts (30 on the bottom side), 70 nets.

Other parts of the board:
C201: 100n; C_0201_0603Metric

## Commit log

2023-04-16 schematic first commit
    [1S_Charger.kicad_sch, Connectors.kicad_sch, ESP32S2FH4S2.kicad_sch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]
2023-04-17 moved files
    [1S_Charger.kicad_sch, Connectors.kicad_sch, ESP32S2FH4S2.kicad_sch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]
2023-04-17 added SPI Bus
    [1S_Charger.kicad_sch, Connectors.kicad_sch, ESP32S2FH4S2.kicad_sch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]
2023-04-18 working on schematic
    [1S_Charger.kicad_sch, Connectors.kicad_sch, ESP32S2FH4S2.kicad_sch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]
2023-04-25 lots of work on routing
    [1S_Charger.kicad_sch, Connectors.kicad_sch, ESP32S2FH4S2.kicad_sch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]
2023-04-28 led footprint update
    [1S_Charger.kicad_sch, ESP32S2FH4S2.kicad_sch, ESP_S2_SoM_HW00.kicad_pcb]
2023-04-28 working on routing
    [ESP_S2_SoM_HW00.kicad_pcb]
2023-12-27 Started nRF52
    [1S_Charger.kicad_sch, Connectors.kicad_sch, ESP32S2FH4S2.kicad_sch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]
2024-01-21 Working on PSoM ESP32S2
    [Connectors.kicad_sch, ESP_S2_SoM_HW00.kicad_pcb, ESP_S2_SoM_HW00.kicad_sch]
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2024-01-31 ESP32 data is done
    [Connectors.kicad_sch, ESP_S2_SoM_HW00.kicad_pcb]
2024-02-03 working on power routing
    [Connectors.kicad_sch, ESP_S2_SoM_HW00.kicad_pcb, bom.csv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]
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2024-02-05 Routing done, ready for prod
    [ESP_S2_SoM_HW00.kicad_pcb, bom.csv, designators.csv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]
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2024-02-08 Added mecha export from PCB
    [2450AT18A100E.sldasm, B3U-1000P.sldasm, COMPOUND.sldprt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]
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2024-02-20 updated prod files + holes are M1.6
    [ESP_S2_SoM_HW00.kicad_pcb, bom.csv, designators.csv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]
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2024-02-25 made small mecha adjustement
    [ESP_S2_SoM_HW00.kicad_pcb, PSoM_ESP32S2_00.DXF, PSoM_ESP32S2_00.SLDASM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]
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2024-02-28 updated bas de page
    [1S_Charger.kicad_sch, Connectors.kicad_sch, ESP_S2_SoM_HW00.kicad_pcb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]
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2024-03-18 Adding PICO_D4 SoM
    Created from ESP32S2 project
    Modifying schematics
    Adding specific documentation
    [1S_Charger.kicad_sch, Connectors.kicad_sch, ESP32S2FH4S2.kicad_sch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]
2024-03-26 Small cartouche mistake
    [1S_Charger.kicad_sch, Connectors.kicad_sch, ESP32S2FH4S2.kicad_sch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]
2024-03-26 small adjustements on rp2040 routing
    [Connectors.kicad_sch, PSoM_RP2040_00.kicad_pcb, PSoM_RP2040_00.kicad_sch]
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2024-04-14 First version of schematic Connections
    Done according to definition in pinout.xlsx (available on master)
    Renaming ESP_... to ESP32_...
    [1S_Charger.kicad_sch, Connectors.kicad_sch, ESP32S2FH4S2.kicad_sch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]
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2024-10-02 added quartz + matching circuit for nrf52 psom
    [nRF52840.kicad_sch]
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2024-10-09 updated ESP32_PICO_D4 schematic page
    [1S_Charger.kicad_sch, Connectors.kicad_sch, ESP32PICOD4.kicad_sch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]
2024-10-13 Final pinout for PSoM_ESP32_PICO_D4
    [Connectors.kicad_sch, ESP32PICOD4.kicad_sch]
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2024-11-19 added nfc connector + update pinout info
    [PSoM_nRF52840_00.kicad_pcb, Pinout.xlsx, nRF52840.kicad_sch]
2025-02-02 First route for the PICO_D4
    Added .gitignore
    Modify at your own taste, this one will be tricky
    [1S_Charger.kicad_sch, Connectors.kicad_sch, ESP32PICOD4.kicad_sch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]
2025-02-05 IO routes finished
    Still missing the routes for GND and 3.3V
    Tried to adjust the .gitignore, experimental
    [PSoM_ESP32_PICO_D4_00.kicad_pcb]
2025-02-06 moved in the nrf inside of boundries
    [1S_Charger.kicad_sch, Connectors.kicad_sch, PSoM_nRF52840_00.kicad_pcb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]
2025-02-07 routing is doing great progress
    [1S_Charger.kicad_sch, PSoM_nRF52840_00.kicad_pcb, nRF52840.kicad_sch]
2025-02-07 moved a few traces
    [Connectors.kicad_sch, PSoM_nRF52840_00.kicad_pcb]
2025-02-07 schematic should be done
    [1S_Charger.kicad_sch, Connectors.kicad_sch, PSoM_nRF52840_00.kicad_pcb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]
2025-02-09 working on the routing
    [1S_Charger.kicad_sch, PSoM_nRF52840_00.kicad_pcb, Pinout.xlsx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]
2025-02-09 Officially finished first version of PicoD4 PSoM
    Modified .gitignore
    [PSoM_ESP32_PICO_D4_00.kicad_pcb]
2025-02-09 pico d4 routage terminé?
    [ESP32PICOD4.kicad_sch, PSoM_ESP32_PICO_D4_00.kicad_pcb]
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2025-02-10 moved the nrf away from the npm
    [1S_Charger.kicad_sch, Connectors.kicad_sch, PSoM_nRF52840_00.kicad_pcb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]
2025-02-10 moved the nrf away and re routed everything
    [1S_Charger.kicad_sch, PSoM_nRF52840_00.kicad_pcb, PSoM_nRF52840_00.kicad_sch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]
2025-02-11 TODO: RF and GND vias
    [1S_Charger.kicad_sch, PSoM_nRF52840_00.kicad_pcb, nRF52840.kicad_sch]
2025-02-11 havent done much routing here
    [PSoM_nRF52840_00.kicad_pcb]
2025-02-11 rf routing to do
    [PSoM_nRF52840_00.kicad_pcb]
2025-02-11 still need to do rf
    [PSoM_nRF52840_00.kicad_pcb]
2025-02-13 opened ground plane for antenna
    [PSoM_nRF52840_00.kicad_pcb]
2025-02-14 added ufl connector and trace width for 50ohm rf
    [PSoM_nRF52840_00.kicad_pcb, nRF52840.kicad_sch]
2025-02-18 finished routing + generated gerbers
    [PSoM_nRF52840_00.kicad_pcb, bom.csv, designators.csv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]
2025-02-19 did some optimization on nrf52840_00
    [PSoM_nRF52840_00.kicad_pcb]
2025-03-11 added pico d4 production files
    [bom.csv, designators.csv, positions.csv]
2025-06-24 started schematic for PSoM_Carrier_00
    [PSoM_Carrier_00.kicad_pcb, PSoM_Carrier_00.kicad_sch]
2025-06-25 finished schematic started layout
    [PSoM_Carrier_00.kicad_pcb, PSoM_Carrier_00.kicad_sch]
2025-06-26 routing v0 is done
    [PSoM_Carrier_00.kicad_pcb, PSoM_Carrier_00.kicad_sch]
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2025-06-30 routing done, exported gerber file
    [PSoM_Carrier_00.kicad_pcb, PSoM_Carrier_00.kicad_sch, bom.csv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]
